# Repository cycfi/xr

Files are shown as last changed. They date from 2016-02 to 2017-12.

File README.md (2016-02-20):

# xr
XR Extended Response Pickups

The Cycfi XR Extended Response Pickups utilize low-impedance coils (Lo-Z 350Ω to 500Ω DCR) which 
inherently have full frequency response from 20Hz to 20kHz and beyond. Unlike traditional high-
impedance passive pickups there are no big peaks and dips in the spectrum, typically perceived as 
the pickup’s “character”. That does not mean that Lo-Z pickups lack character. In fact a Lo-Z coil’s 
characteristically wide bandwidth gives it a voice all its own. The pickups are very rich in harmonics, 
with uber-clean sounds, lots of overtones and crystal clear highs. They have a lot more harmonic 
content than even the bright Stratocaster pickup (which has frequency response that rolls off at 
around 5KHz.) On the low end of the audio spectrum you get tight, well-defined and focused bass 
all the way down to 20Hz.

This work is licensed under a [Creative Commons Attribution-NonCommercial 4.0 
International License](http://creativecommons.org/licenses/by-nc/4.0/).

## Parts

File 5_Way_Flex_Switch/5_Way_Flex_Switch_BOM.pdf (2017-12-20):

### 5 WAY FLEX SWITCH V1.2

Item | Description | Part Number | Packaging | Manufacturer | Location | Qty.
1 | 5 Way Switch | LSW56 | - | - | - | 1
2 | 2x7 Male Header | M20-9720745 (http://www.mouser.com/ProductDetail/Harwin/M20-9720745/) | 2.54mm | Harwin | H1 | 1
3 | 2x4 Male Header | M20-9720445 (http://www.mouser.ph/ProductDetail/Harwin/M20-9720445/) | 2.54mm | Harwin | H2 | 1
4 | 1x3 SMD Male Header | M20-8900305 (http://www.mouser.ph/ProductDetail/Harwin/M20-8900305/) | 2.54mm | Harwin | H3 | 1
5 | 4.7uF | GRM188R61C475KAAJD (http://www.mouser.com/ProductDetail/Murata-Electronics/GRM188R61C475KAAJD/) | SMD 0603 | Murata | C1 | 1
6 | 0.1uF | VJ0603Y104JXJPW1BC (http://www.mouser.com/ProductDetail/Vishay/VJ0603Y104JXJPW1BC/) | SMD 0603 | Vishay | C2 | 1
7 | Shunt | M7582-05 (http://www.mouser.com/ProductDetail/Harwin/M7582-05/) | 2.54mm | Harwin | - | 1

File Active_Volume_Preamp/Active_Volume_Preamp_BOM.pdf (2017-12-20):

ACTIVE VOLUME PREAMP V1.1
Item | Description | Part Number | Packaging | Manufacturer | Location | Qty.
1 | 25K Potentiometer | PDB241-GTR01-253A2 (http://www.mouser.com/ProductDetail/Bourns/PDB241-GTR01-253A2/) | - | Bourns | POT1 | 1
2 | 500 ohms Trimmer | TC33X-2-501E (http://www.mouser.com/ProductDetail/Bourns/TC33X-2-501E/?qs=uk4CKxxanjz26UifkfMmKw%3D%3D) | SMD | Bourns | TR1 | 1
3 | 2x7 Male Header RA | M20-9950745 (http://www.mouser.com/ProductDetail/Harwin/M20-9950745/) | 2.54mm TH | Harwin | H1 | 1
4 | Shunt | M7582-05 (http://www.mouser.com/ProductDetail/Harwin/M7582-05/) | 2.54mm | Harwin | - | 1

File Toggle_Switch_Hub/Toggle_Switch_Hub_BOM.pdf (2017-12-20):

TOGGLE SWITCH HUB V1.1
Item | Description | Part Number | Packaging | Manufacturer | Location | Qty.
1 | 2x5 Male Header | M20-9720545 (http://www.mouser.ph/ProductDetail/Harwin/M20-9720545/) | 2.54mm | Harwin | H1 | 1
2 | 2x4 Male Header | M20-9720445 (http://www.mouser.ph/ProductDetail/Harwin/M20-9720445/) | 2.54mm | Harwin | H2 | 1
3 | 1x8 Male Header | M20-9730845 (http://www.mouser.ph/Search/ProductDetail.aspx) | 2.54mm | Harwin | H3 | 2
4 | Terminal Block | 282837-4 (http://www.mouser.ph/Search/ProductDetail.aspx?R=282837-4virtualkey57110000virtualkey571-2828374) | 5.08mm | TE Connectivity | TB1 | 1
5 | 4.7uF | GRM188R61C475KAAJD (http://www.mouser.com/ProductDetail/Murata-Electronics/GRM188R61C475KAAJD/) | SMD 0603 | Murata | C1 | 1
6 | 0.1uF | VJ0603Y104JXJPW1BC (http://www.mouser.com/ProductDetail/Vishay/VJ0603Y104JXJPW1BC/) | SMD 0603 | Vishay | C2 | 1
7 | Shunt | M7582-05 (http://www.mouser.com/ProductDetail/Harwin/M7582-05/) | 2.54mm | Harwin | - | 4

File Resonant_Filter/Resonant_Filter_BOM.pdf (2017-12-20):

RESONANT FILTER
Item | Description | Part Number | Packaging | Manufacturer | Location | Qty.
1 | 100K Potentiometer | PDB182-GTR01-104B0 (http://www.mouser.ph/ProductDetail/Bourns/PDB182-GTR01-104B0/) | - | Bourns | - | 2
2 | 0.1uF | VJ0603Y104JXJPW1BC (http://www.mouser.ph/ProductDetail/Vishay-Vitramon/VJ0603Y104JXJPW1BC/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) | SMD 0603 | Vishay | C1, C3 | 2
3 | 4.7uF | C1608X5R1C475M080AC (http://www.mouser.ph/ProductDetail/TDK/C1608X5R1C475M080AC/) | SMD 0603 | TDK | C4 | 1
4 | 100pF | VJ0805A101GXAPW1BC (http://www.mouser.ph/ProductDetail/Vishay-Vitramon/VJ0805A101GXAPW1BC/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) | SMD 0805 | Vishay | C6 | 1
5 | 1uF | VJ0805Y105KXQTW1BC (http://www.mouser.ph/ProductDetail/Vishay-Vitramon/VJ0805Y105KXQTW1BC/) | SMD 0805 | Vishay | C2, C5 | 2
6 | 4.7K | CRCW04024K70JNED (http://www.mouser.ph/ProductDetail/Vishay-Dale/CRCW04024K70JNED/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) | SMD 0402 | Vishay | R7 | 1
7 | 20K | CRCW040220K0JNED (http://www.mouser.ph/ProductDetail/Vishay-Dale/CRCW040220K0JNED/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) | SMD 0402 | Vishay | R4 | 1
8 | 47K | CRCW040247K0JNED (http://www.mouser.ph/ProductDetail/Vishay-Dale/CRCW040247K0JNED/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) | SMD 0402 | Vishay | R6 | 1
9 | 60.4K | TNPW040260K4BEED (http://www.mouser.ph/ProductDetail/Vishay/TNPW040260K4BEED/) | SMD 0402 | Vishay | R5 | 1
10 | 100K | RT0402FRE07100KL (http://www.mouser.ph/ProductDetail/Yageo/RT0402FRE07100KL/) | SMD 0402 | Yageo | R2, R3 | 2
11 | 150K | CRCW0402150KFKED (http://www.mouser.ph/ProductDetail/Vishay-Dale/CRCW0402150KFKED/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) | SMD 0402 | Vishay | R1 | 1
12 | 100K | RT0402FRE07100KL (http://www.mouser.ph/ProductDetail/Yageo/RT0402FRE07100KL/) | SMD 0402 | Yageo | R10, R11 | 2
13 | 3.3K | RT0603FRE073K3L (http://www.mouser.ph/ProductDetail/Yageo/RT0603FRE073K3L/) | SMD 0603 | Yageo | R8, R9 | 2
14 | 3.3nF | VJ0805Y332JXACW1B (http://www.mouser.ph/ProductDetail/Vishay-Vitramon/VJ0805Y332JXACW1BC/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) | SMD 0805 | Vishay | C7, C8 | 2
15 | 2SC3324 | 2SC3324GRTE85LF (http://www.mouser.ph/ProductDetail/Toshiba/2SC3324GRTE85LF/) | SOT 23 | Toshiba | T1 | 1
16 | OPA209 | OPA209AIDBVR (http://www.mouser.ph/ProductDetail/Texas-Instruments/OPA209AIDBVR/) | SOT23-5 | Texas Instruments | U1 | 1
17 | 1x8 Male Header, RA | M20-9960845 (http://www.mouser.ph/ProductDetail/Harwin/M20-9960845/) | 2.54mm | Harwin | H1 | 1
18 | 1x4 Male Header | M20-9730445 (http://www.mouser.ph/ProductDetail/Harwin/M20-9730445/) | 2.54mm | Harwin | H2 | 1

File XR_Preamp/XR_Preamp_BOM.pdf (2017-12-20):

XR UNIVERSAL PREAMP V.1.5
Item | Description | Part Number | Packaging | Manufacturer | Location | Qty.
1 | 0.1uF | GRM155R71C104KA88D (http://www.mouser.com/Search/ProductDetail.aspx) | SMD 0402 | Murata | C4 | 1
2 | 100pF | C0402C101K4GACTU (http://www.mouser.com/Search/ProductDetail.aspx) | SMD 0402 | Kemet | C2 | 1
3 | 10k | RC0402FR-0710KL (http://www.mouser.com/Search/ProductDetail.aspx) | SMD 0402 | Yageo | R4, R5 | 2
4 | 1k | RC0402FR-071KL (http://www.mouser.com/Search/ProductDetail.aspx) | SMD 0402 | Yageo | R7 | 1
5 | 200k | MCS04020C2003FE000 (http://www.mouser.com/ProductDetail/Vishay-Beyschlag/MCS04020C2003FE000/) | SMD 0402 | Vishay | R1 | 1
6 | 22k | RR0510P-223-D (http://www.mouser.com/ProductDetail/Susumu/RR0510P-223-D/) | SMD 0402 | Susumu | R3 | 1
7 | 27k | RR0510P-273-D (http://www.mouser.com/ProductDetail/Susumu/RR0510P-273-D/) | SMD 0402 | Susumu | R2 | 1
8 | 2SC3324 | 2SC3324GRTE85LF (http://www.mouser.com/Search/ProductDetail.aspx) | SOT23 | Toshiba | T1, T2 | 2
9 | 4.7k | RR0510P-472-D (http://www.mouser.com/ProductDetail/Susumu/RR0510P-472-D/) | SMD 0402 | Susumu | R6 | 1
10 | 4.7uF | ZRB15XR61A475ME01D (http://www.mouser.com/ProductDetail/Murata-Electronics/ZRB15XR61A475ME01D/) | SMD 0402 | Murata | C5 | 1
11 | 4.7uF | GRM188R61C475KAAJD (http://www.mouser.com/Search/ProductDetail.aspx) | SMD 0603 | Murata | C1, C3 | 2

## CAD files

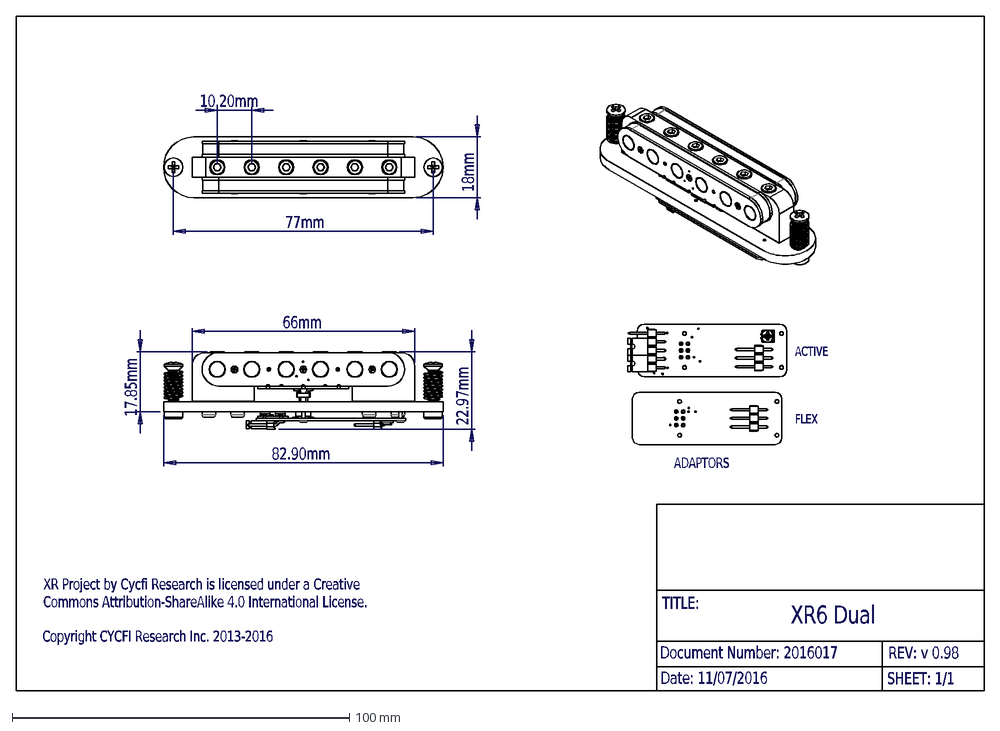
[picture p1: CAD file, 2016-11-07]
CAD_Drawings/XR_Dual/XR6_Dual_Drawing.dxf
FLEX
XR Project by Cycfi Research is licensed under a Creative
Commons Attribution-ShareAlike 4.0 International License.
Copyright CYCFI Research Inc. 2013-2016
XR6 Dual
TITLE:
Document Number: 2016017
Date: 11/07/2016
REV: v 0.98
SHEET: 1/1
66mm
82.90mm
22.97mm
17.85mm
77mm
10.20mm
18mm
ACTIVE
ADAPTORS

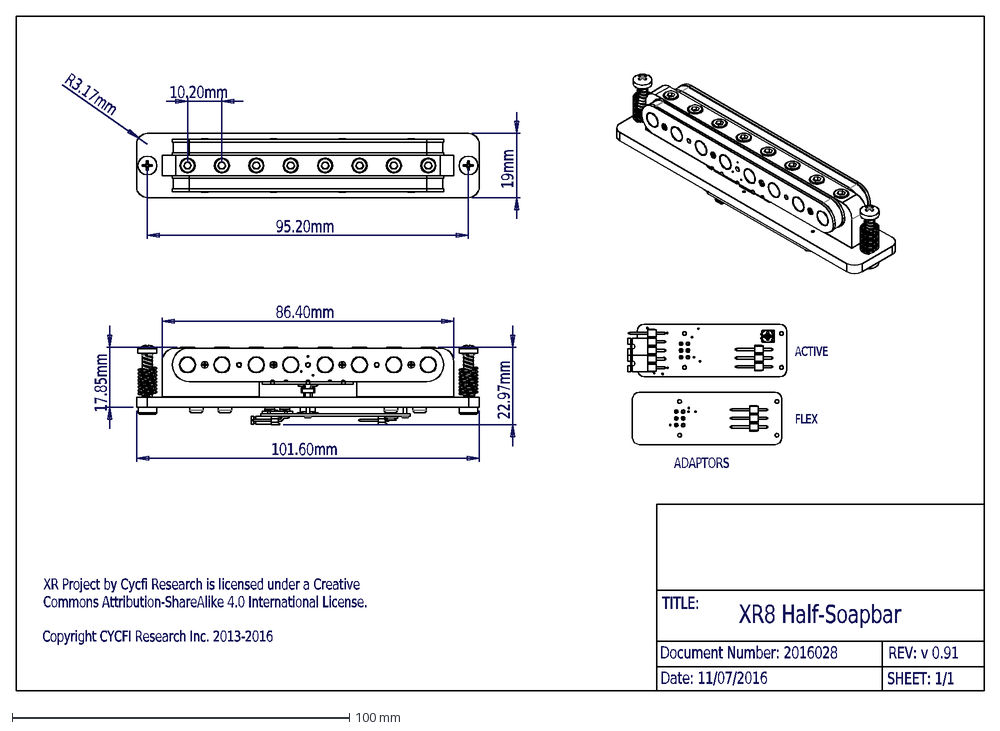
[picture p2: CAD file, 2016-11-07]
CAD_Drawings/XR_Half_Soapbar/XR8_Half_Soapbar_Drawing.dxf
FLEX
XR Project by Cycfi Research is licensed under a Creative
Commons Attribution-ShareAlike 4.0 International License.
Copyright CYCFI Research Inc. 2013-2016
XR8 Half-Soapbar
TITLE:
Document Number: 2016028
Date: 11/07/2016
REV: v 0.91
SHEET: 1/1
22.97mm
86.40mm
17.85mm
101.60mm
10.20mm
95.20mm
19mm
R3.17mm
ACTIVE
ADAPTORS

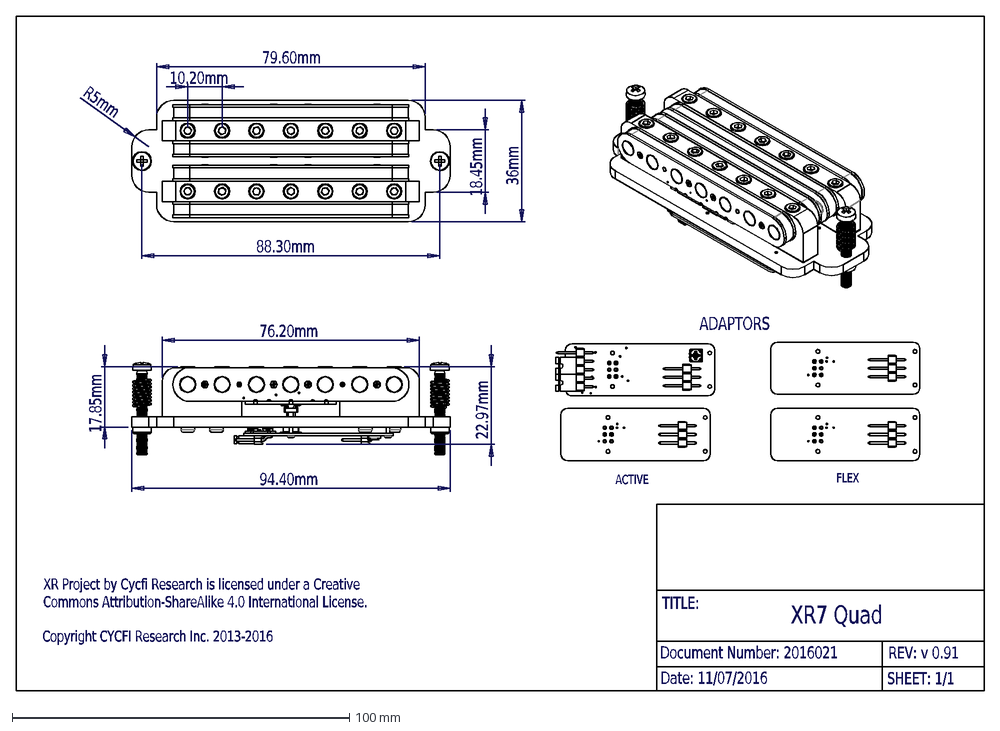
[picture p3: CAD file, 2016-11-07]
CAD_Drawings/XR_Quad/XR7_Quad_Drawing.dxf
FLEX
XR Project by Cycfi Research is licensed under a Creative
Commons Attribution-ShareAlike 4.0 International License.
Copyright CYCFI Research Inc. 2013-2016
XR7 Quad
TITLE:
Document Number: 2016021
Date: 11/07/2016
REV: v 0.91
SHEET: 1/1
94.40mm
76.20mm
22.97mm
17.85mm
88.30mm
10.20mm
79.60mm
18.45mm
36mm
R5mm
ACTIVE
ADAPTORS

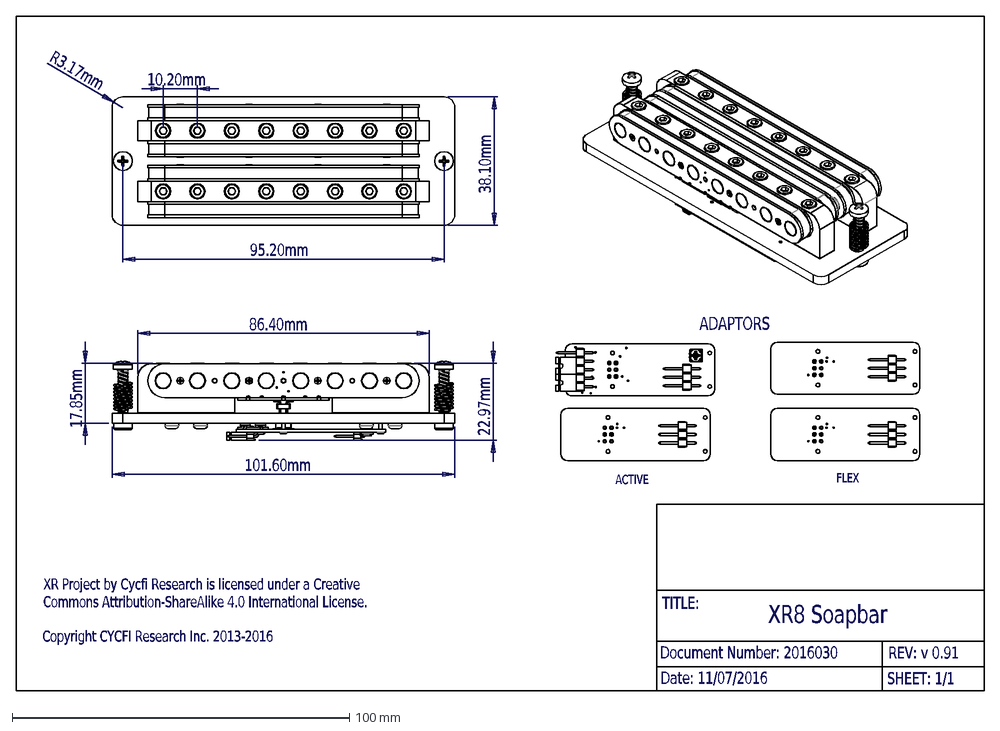
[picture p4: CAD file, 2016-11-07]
CAD_Drawings/XR_Soapbar/XR8_Soapbar_Drawing.DXF
FLEX
XR Project by Cycfi Research is licensed under a Creative
Commons Attribution-ShareAlike 4.0 International License.
Copyright CYCFI Research Inc. 2013-2016
XR8 Soapbar
TITLE:
Document Number: 2016030
Date: 11/07/2016
REV: v 0.91
SHEET: 1/1
86.40mm
22.97mm
101.60mm
17.85mm
10.20mm
38.10mm
R3.17mm
95.20mm
ACTIVE
ADAPTORS

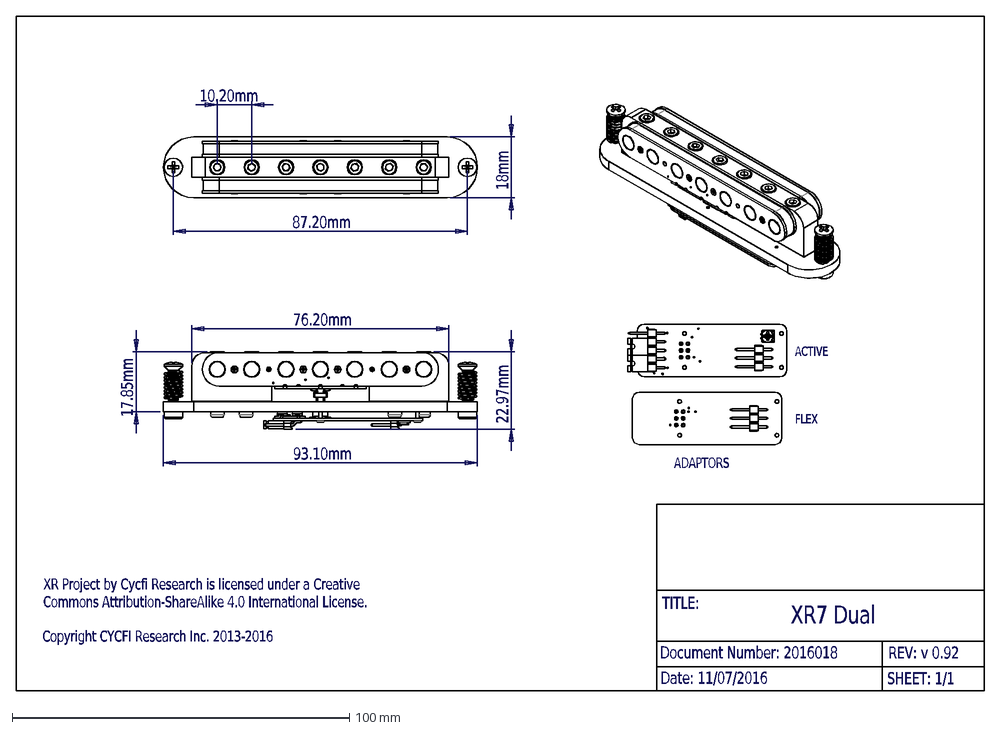
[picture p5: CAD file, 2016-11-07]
CAD_Drawings/XR_Dual/XR7_Dual_Drawing.dxf
FLEX
XR Project by Cycfi Research is licensed under a Creative
Commons Attribution-ShareAlike 4.0 International License.
Copyright CYCFI Research Inc. 2013-2016
XR7 Dual
TITLE:
Document Number: 2016018
Date: 11/07/2016
REV: v 0.92
SHEET: 1/1
76.20mm
93.10mm
22.97mm
17.85mm
87.20mm
10.20mm
18mm
ACTIVE
ADAPTORS

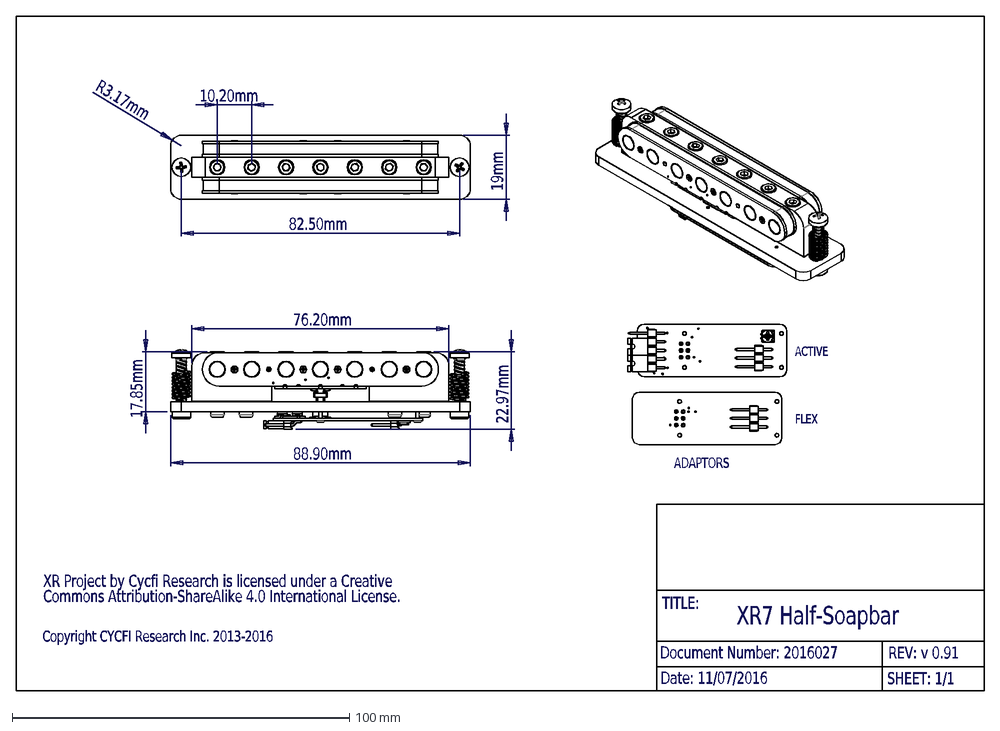
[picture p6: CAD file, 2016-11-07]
CAD_Drawings/XR_Half_Soapbar/XR7_Half_Soapbar_Drawing.dxf
FLEX
XR Project by Cycfi Research is licensed under a Creative
Commons Attribution-ShareAlike 4.0 International License.
Copyright CYCFI Research Inc. 2013-2016
XR7 Half-Soapbar
TITLE:
Document Number: 2016027
Date: 11/07/2016
REV: v 0.91
SHEET: 1/1
76.20mm
22.97mm
17.85mm
88.90mm
10.20mm
19mm
82.50mm
R3.17mm
ACTIVE
ADAPTORS

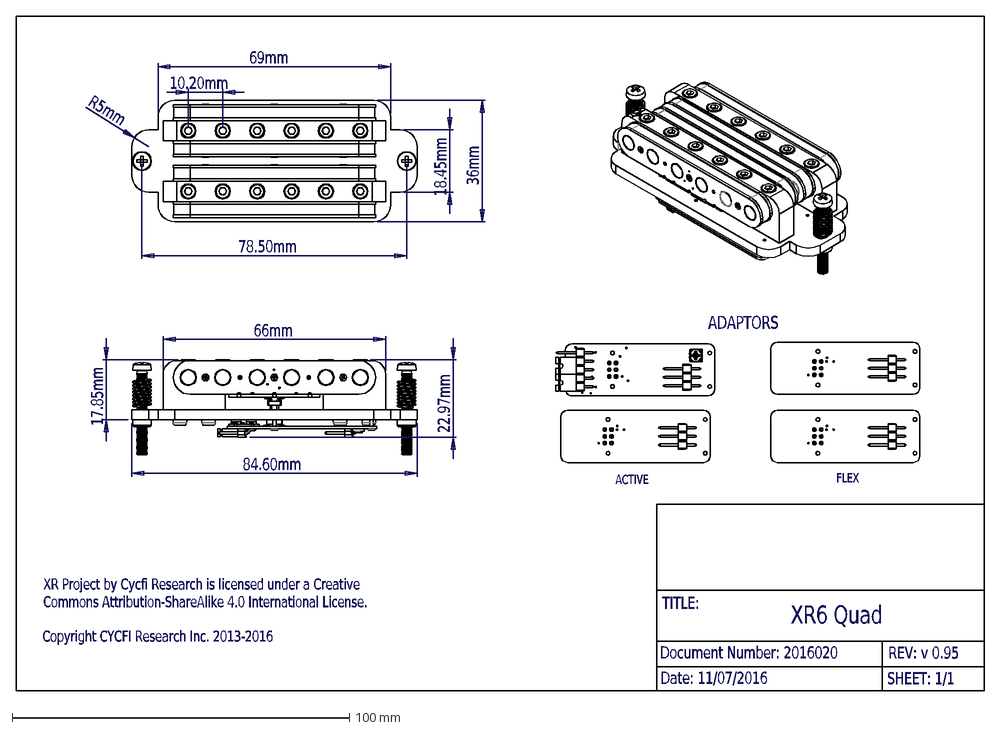
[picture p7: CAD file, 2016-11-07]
CAD_Drawings/XR_Quad/XR6_Quad_Drawing.dxf
FLEX
XR Project by Cycfi Research is licensed under a Creative
Commons Attribution-ShareAlike 4.0 International License.
Copyright CYCFI Research Inc. 2013-2016
XR6 Quad
TITLE:
Document Number: 2016020
Date: 11/07/2016
REV: v 0.95
SHEET: 1/1
66mm
22.97mm
84.60mm
17.85mm
10.20mm
69mm
18.45mm
36mm
78.50mm
R5mm
ACTIVE
ADAPTORS

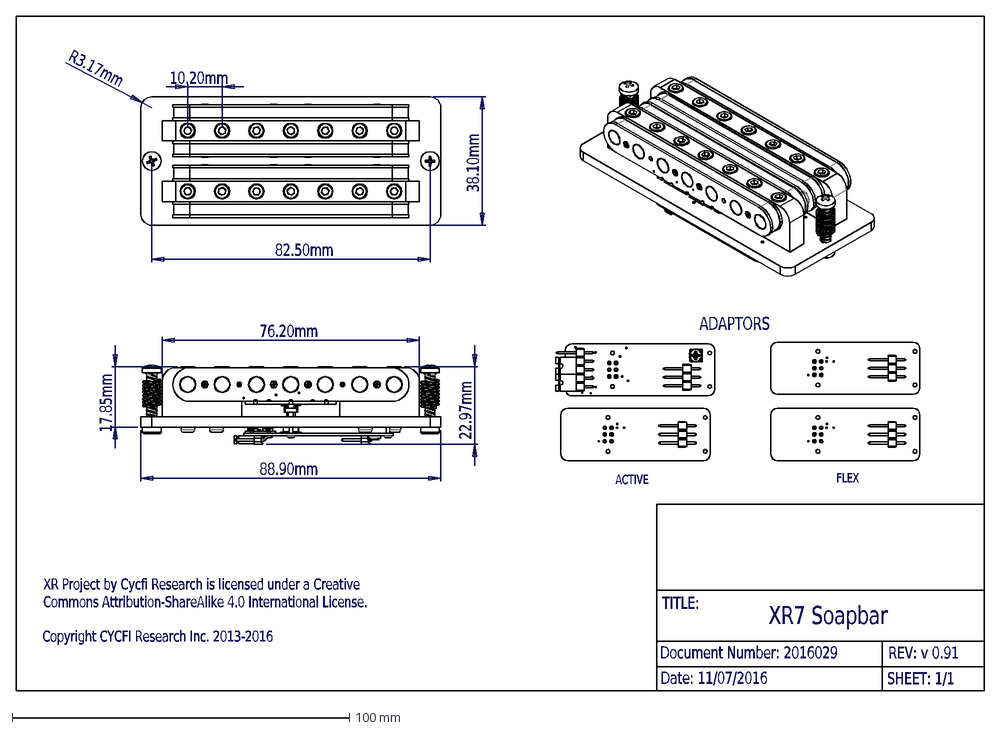
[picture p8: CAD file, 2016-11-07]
CAD_Drawings/XR_Soapbar/XR7_Soapbar_Drawing.DXF
FLEX
XR Project by Cycfi Research is licensed under a Creative
Commons Attribution-ShareAlike 4.0 International License.
Copyright CYCFI Research Inc. 2013-2016
XR7 Soapbar
TITLE:
Document Number: 2016029
Date: 11/07/2016
REV: v 0.91
SHEET: 1/1
76.20mm
22.97mm
88.90mm
17.85mm
10.20mm
38.10mm
82.50mm
R3.17mm
ACTIVE
ADAPTORS

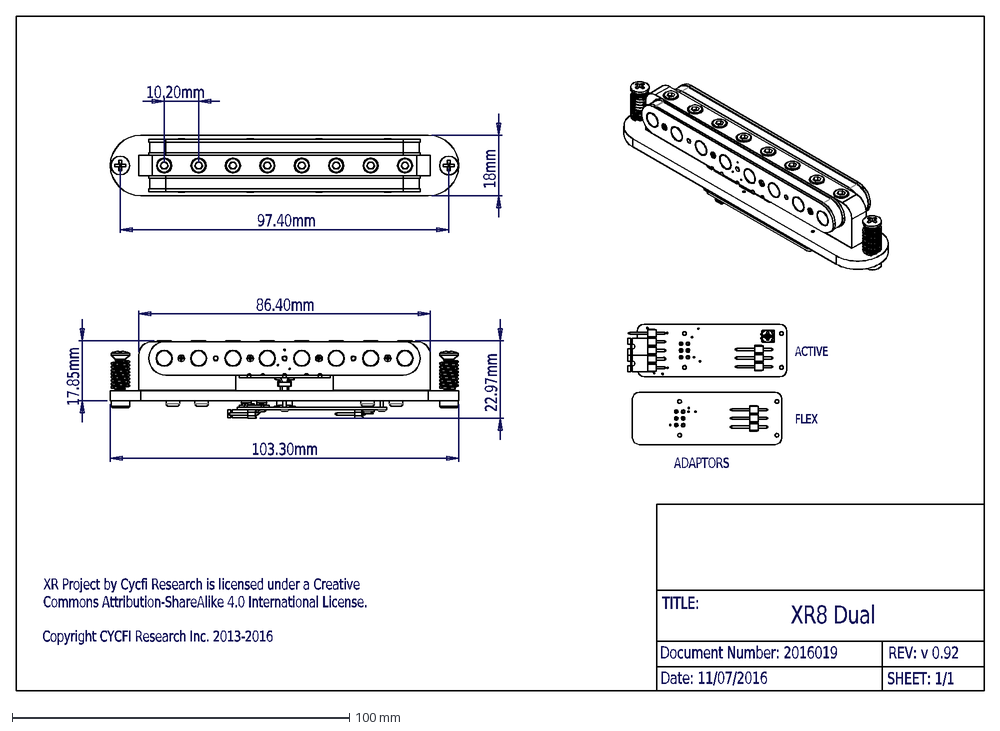
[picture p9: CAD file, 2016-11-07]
CAD_Drawings/XR_Dual/XR8_Dual_Drawing.dxf
FLEX
XR Project by Cycfi Research is licensed under a Creative
Commons Attribution-ShareAlike 4.0 International License.
Copyright CYCFI Research Inc. 2013-2016
XR8 Dual
TITLE:
Document Number: 2016019
Date: 11/07/2016
REV: v 0.92
SHEET: 1/1
17.85mm
22.97mm
86.40mm
103.30mm
97.40mm
10.20mm
18mm
ACTIVE
ADAPTORS

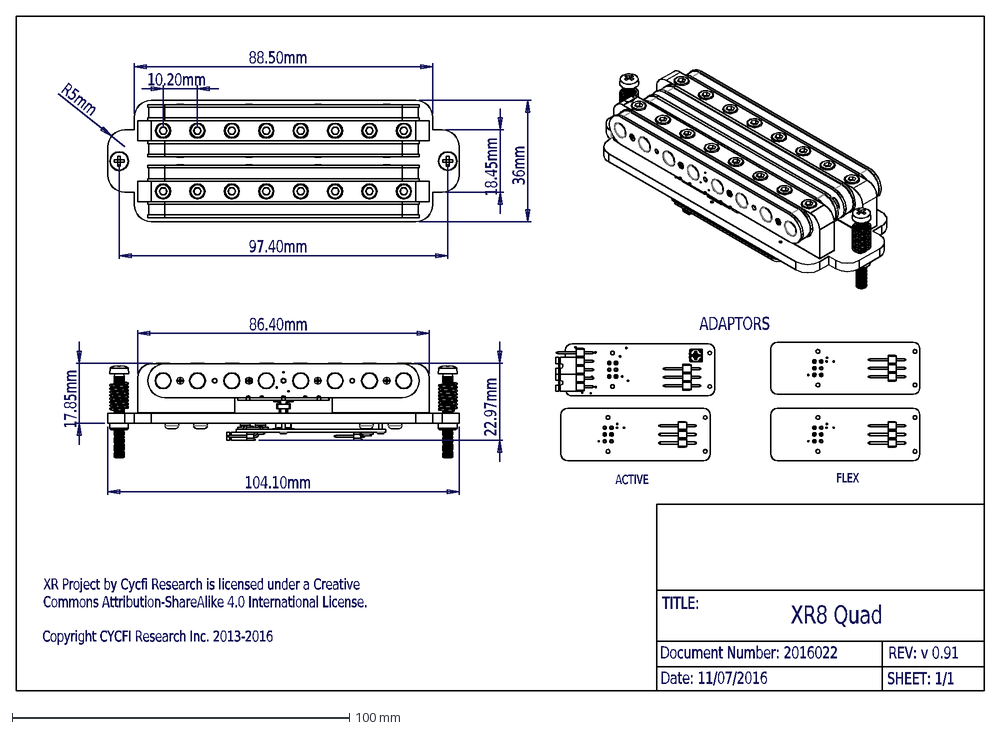
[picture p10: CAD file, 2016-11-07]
CAD_Drawings/XR_Quad/XR8_Quad_Drawing.dxf
FLEX
XR Project by Cycfi Research is licensed under a Creative
Commons Attribution-ShareAlike 4.0 International License.
Copyright CYCFI Research Inc. 2013-2016
XR8 Quad
TITLE:
Document Number: 2016022
Date: 11/07/2016
REV: v 0.91
SHEET: 1/1
86.40mm
104.10mm
17.85mm
22.97mm
97.40mm
88.50mm
10.20mm
36mm
18.45mm
R5mm
ACTIVE
ADAPTORS

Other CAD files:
CAD_Drawings/Baseplate/Half_Soapbar.DXF
CAD_Drawings/Baseplate/Soapbar.dxf
CAD_Drawings/Baseplate/Dual.dxf
CAD_Drawings/Baseplate/Quad.dxf

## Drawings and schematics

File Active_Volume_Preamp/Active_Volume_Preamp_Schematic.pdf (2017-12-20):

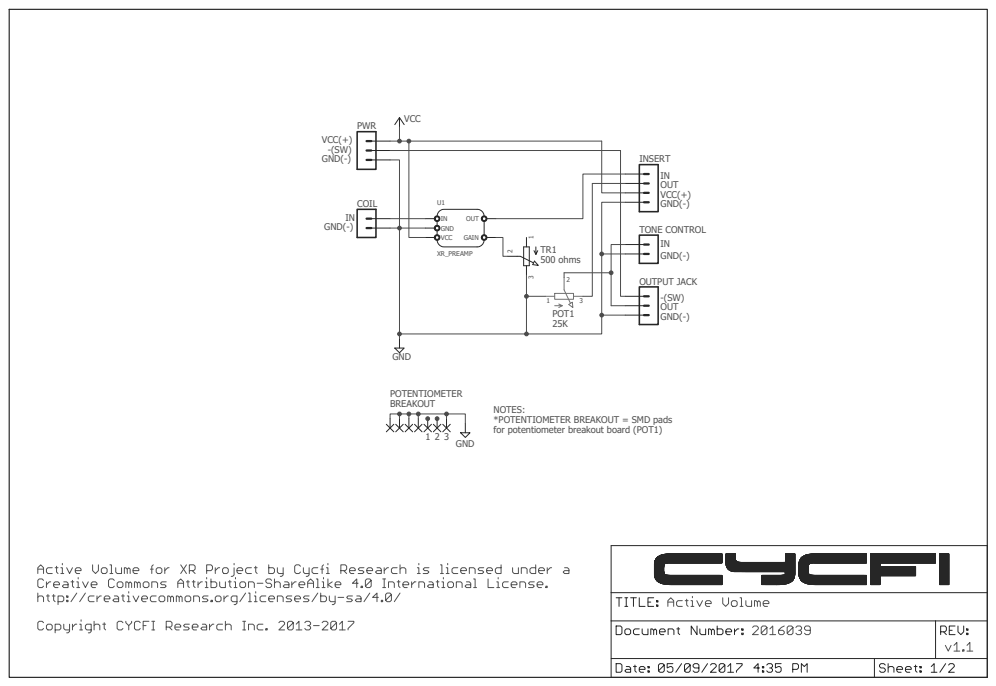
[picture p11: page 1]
GND; VCC; POTENTIOMETER BREAKOUT; POT1 25K; VCC(+); GND(-); IN OUT VCC(+) GND(-); -(SW) OUT GND(-); PWR; INSERT; OUTPUT JACK; COIL; TONE CONTROL IN GND(-); IN GND(-); 500 ohms; IN GND VCC; OUT; GAIN; XR_PREAMP

NOTES:
*POTENTIOMETER BREAKOUT = SMD pads
for potentiometer breakout board (POT1)

# OUTPUT HEADERS

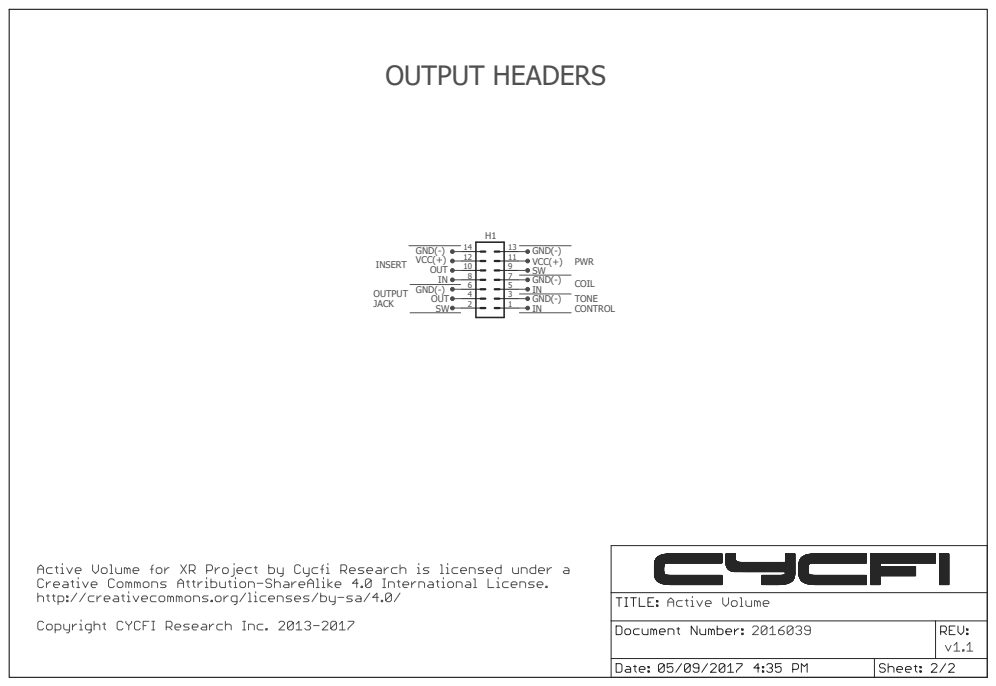
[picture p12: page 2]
OUT; GND(-); VCC(+); INSERT; OUTPUT JACK; PWR; TONE CONTROL; COIL

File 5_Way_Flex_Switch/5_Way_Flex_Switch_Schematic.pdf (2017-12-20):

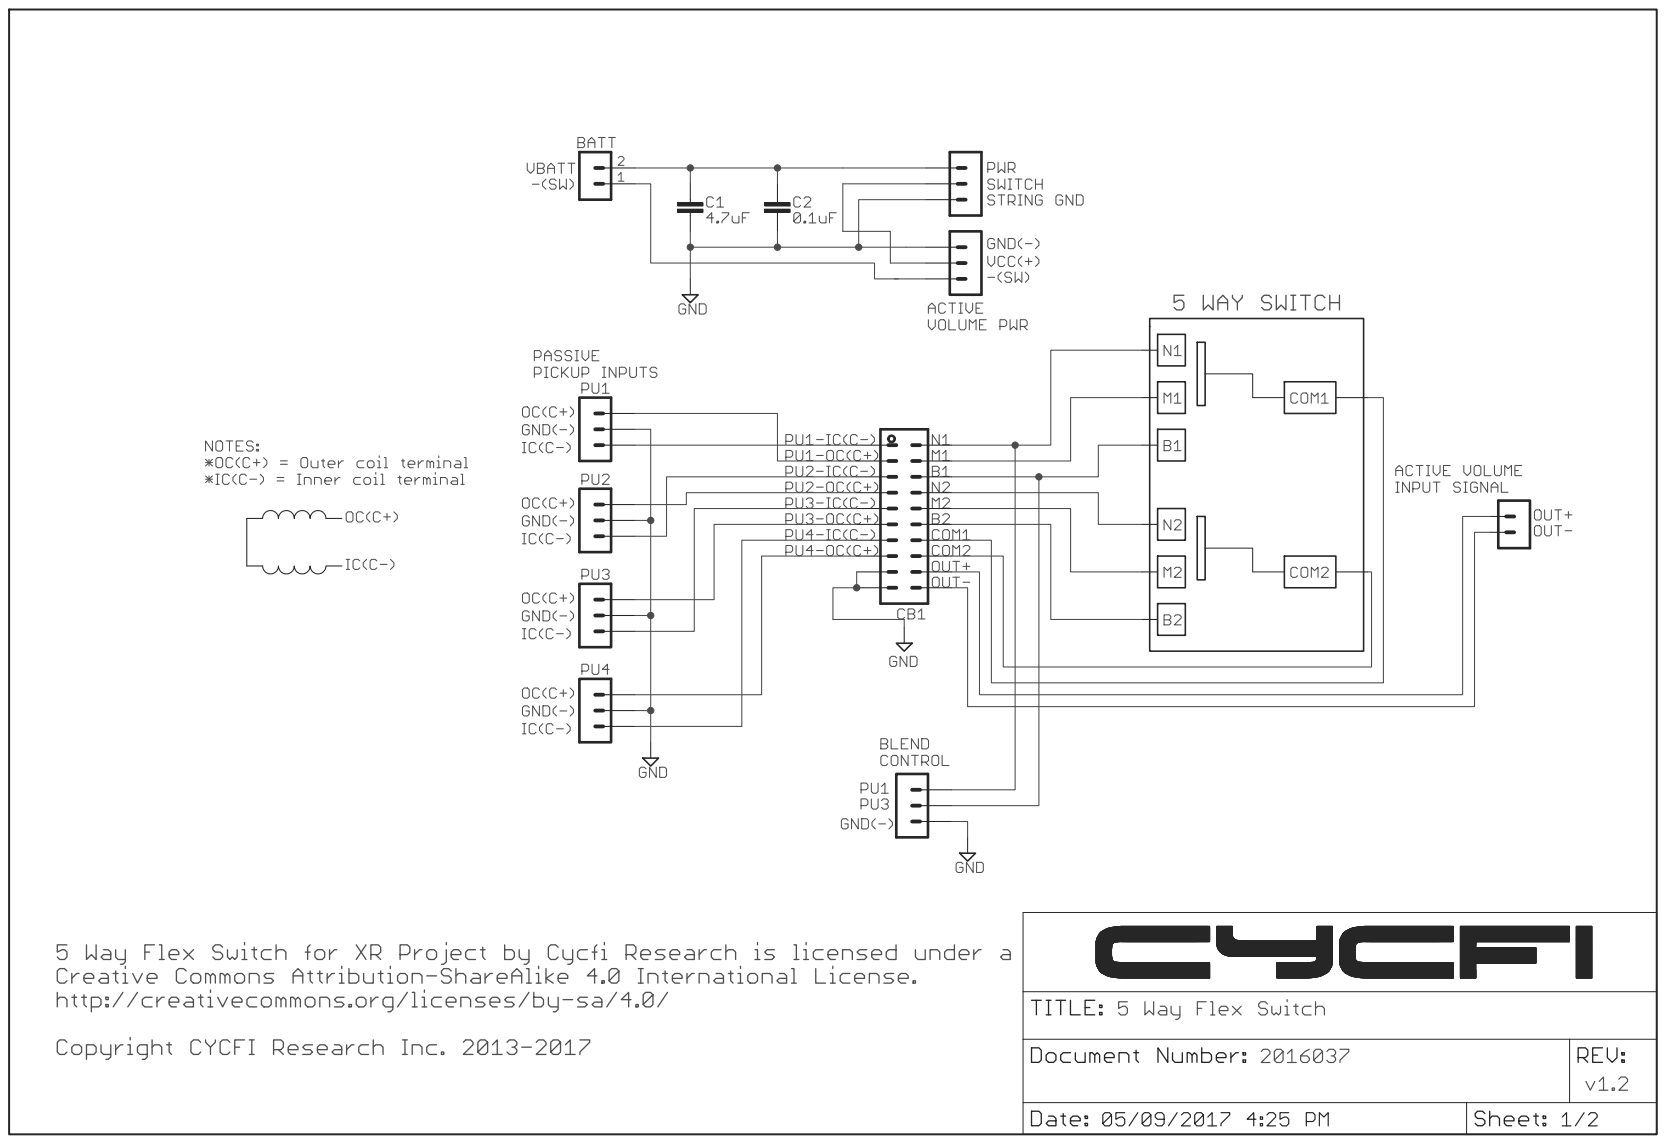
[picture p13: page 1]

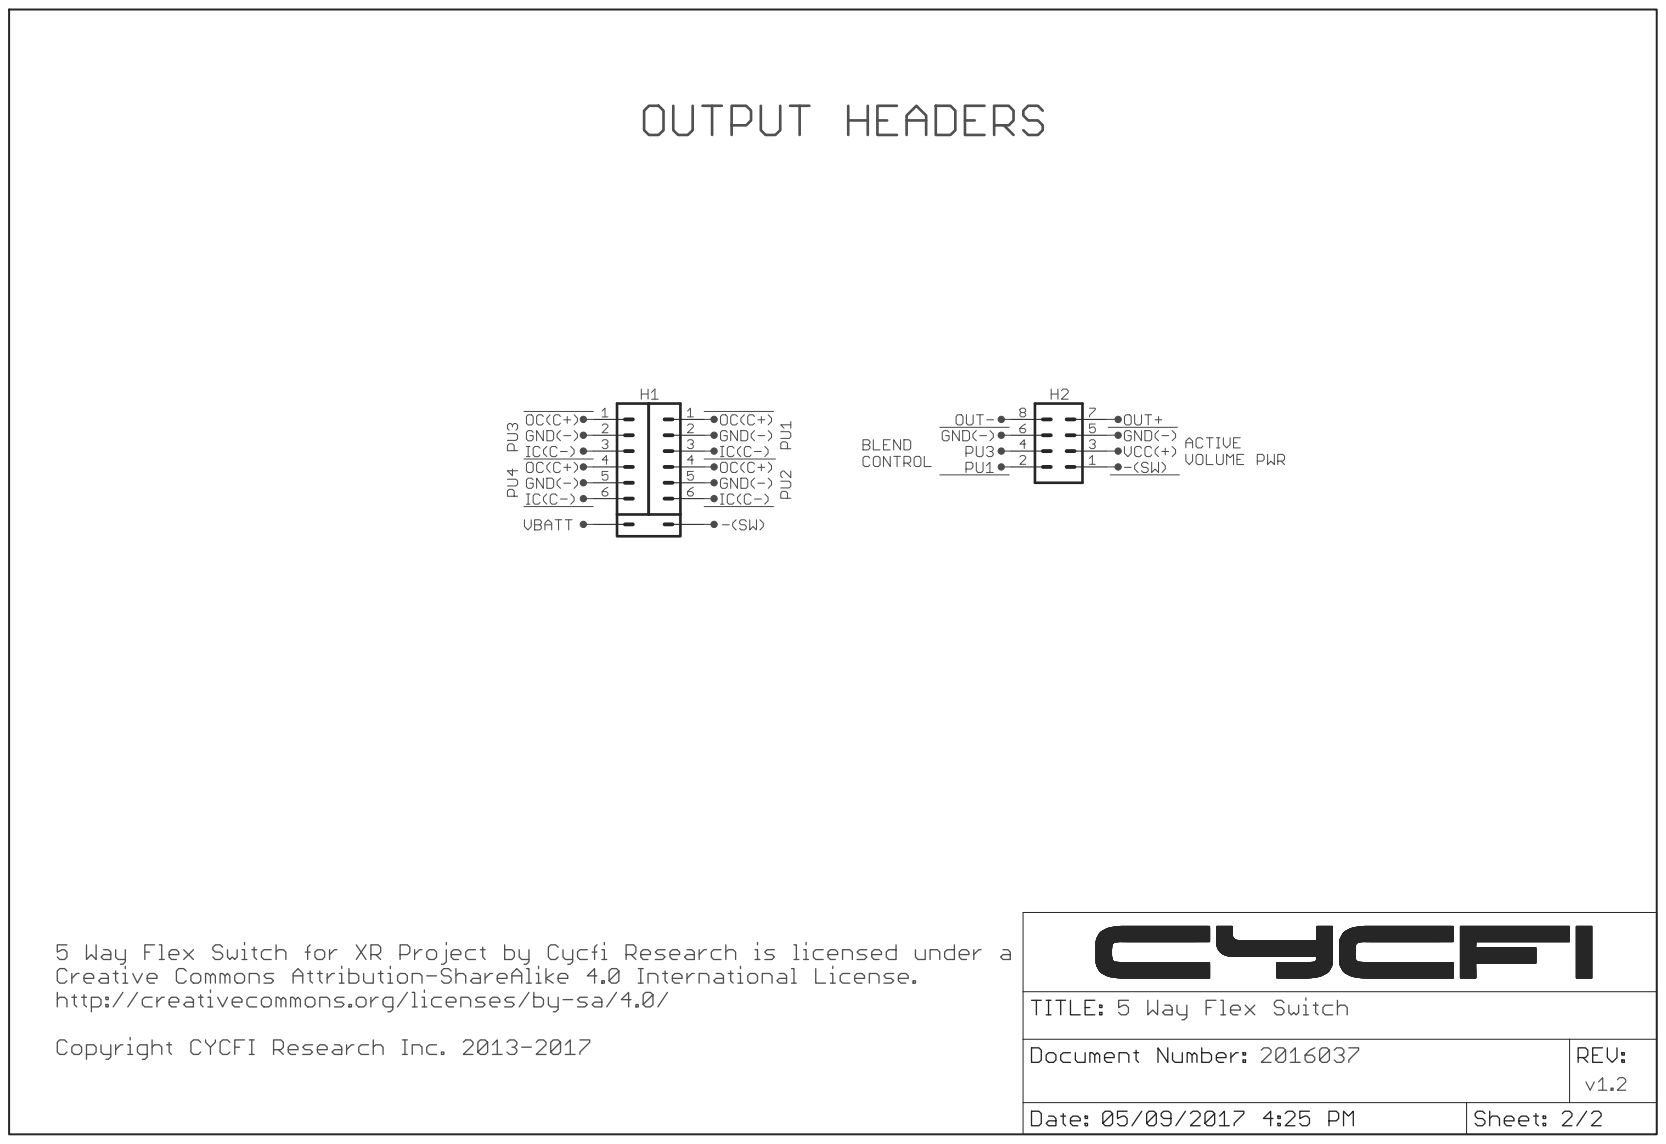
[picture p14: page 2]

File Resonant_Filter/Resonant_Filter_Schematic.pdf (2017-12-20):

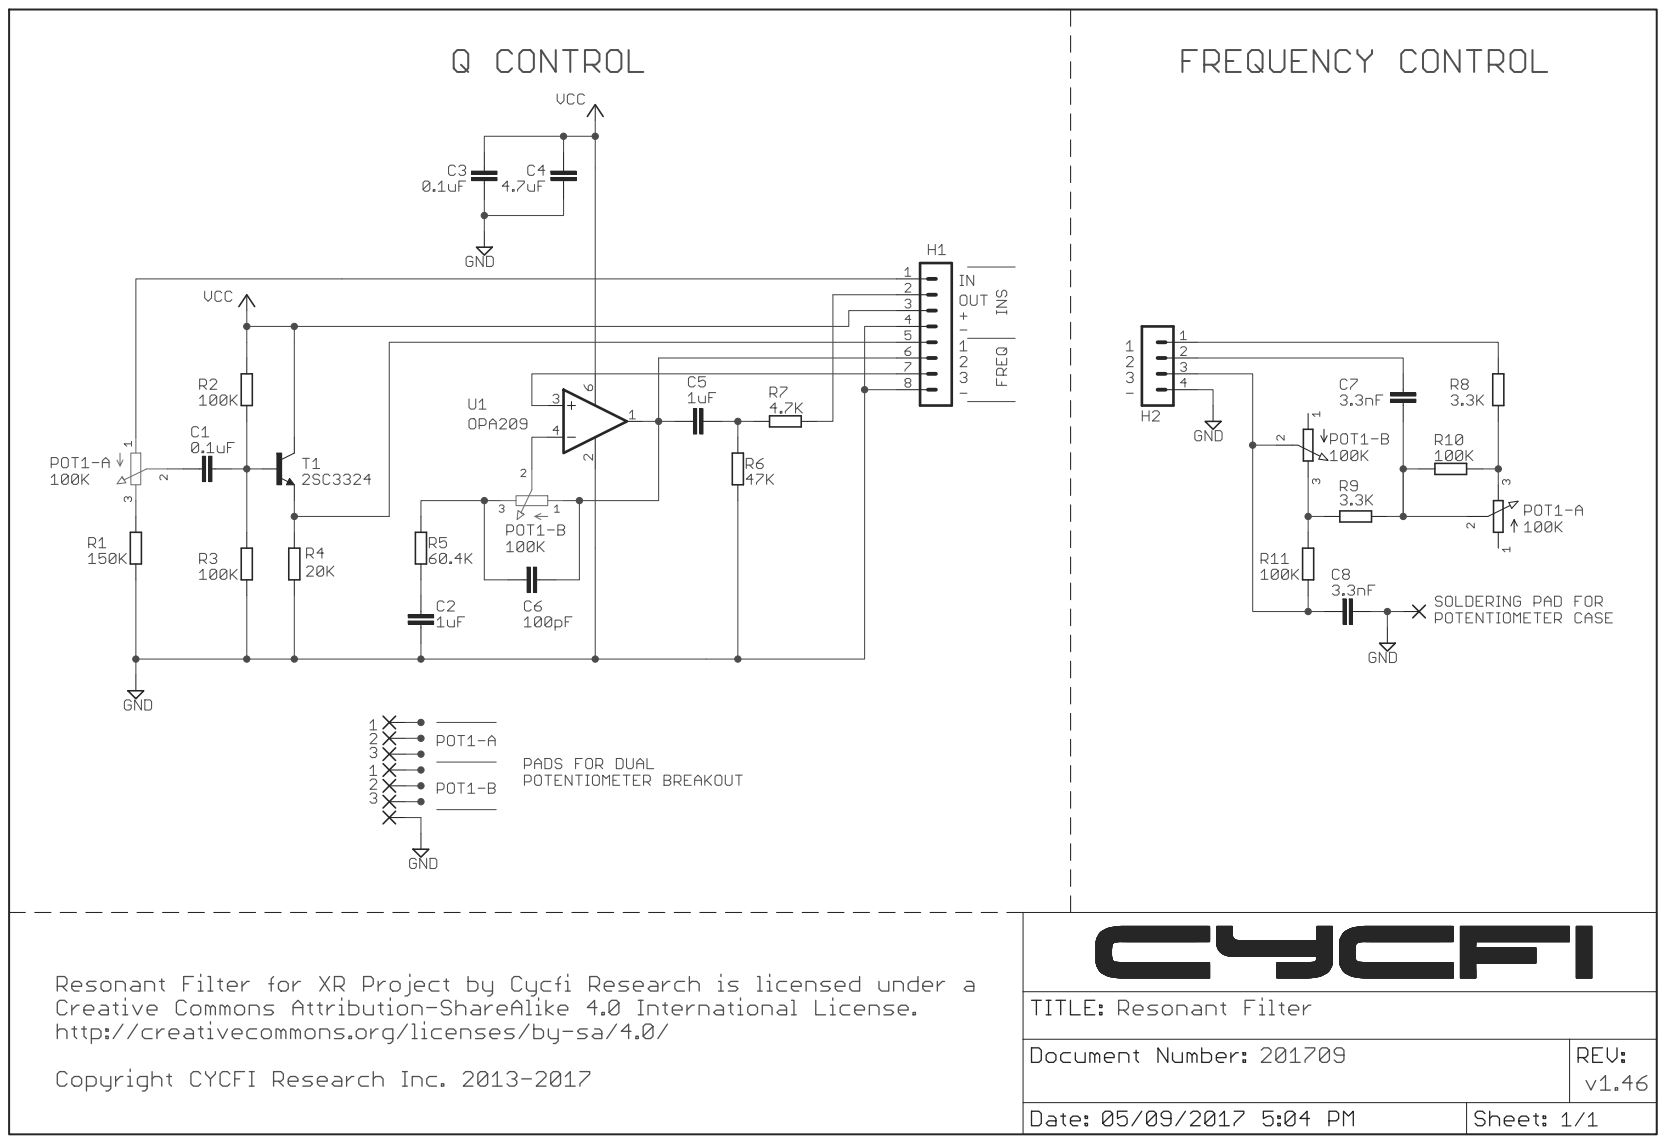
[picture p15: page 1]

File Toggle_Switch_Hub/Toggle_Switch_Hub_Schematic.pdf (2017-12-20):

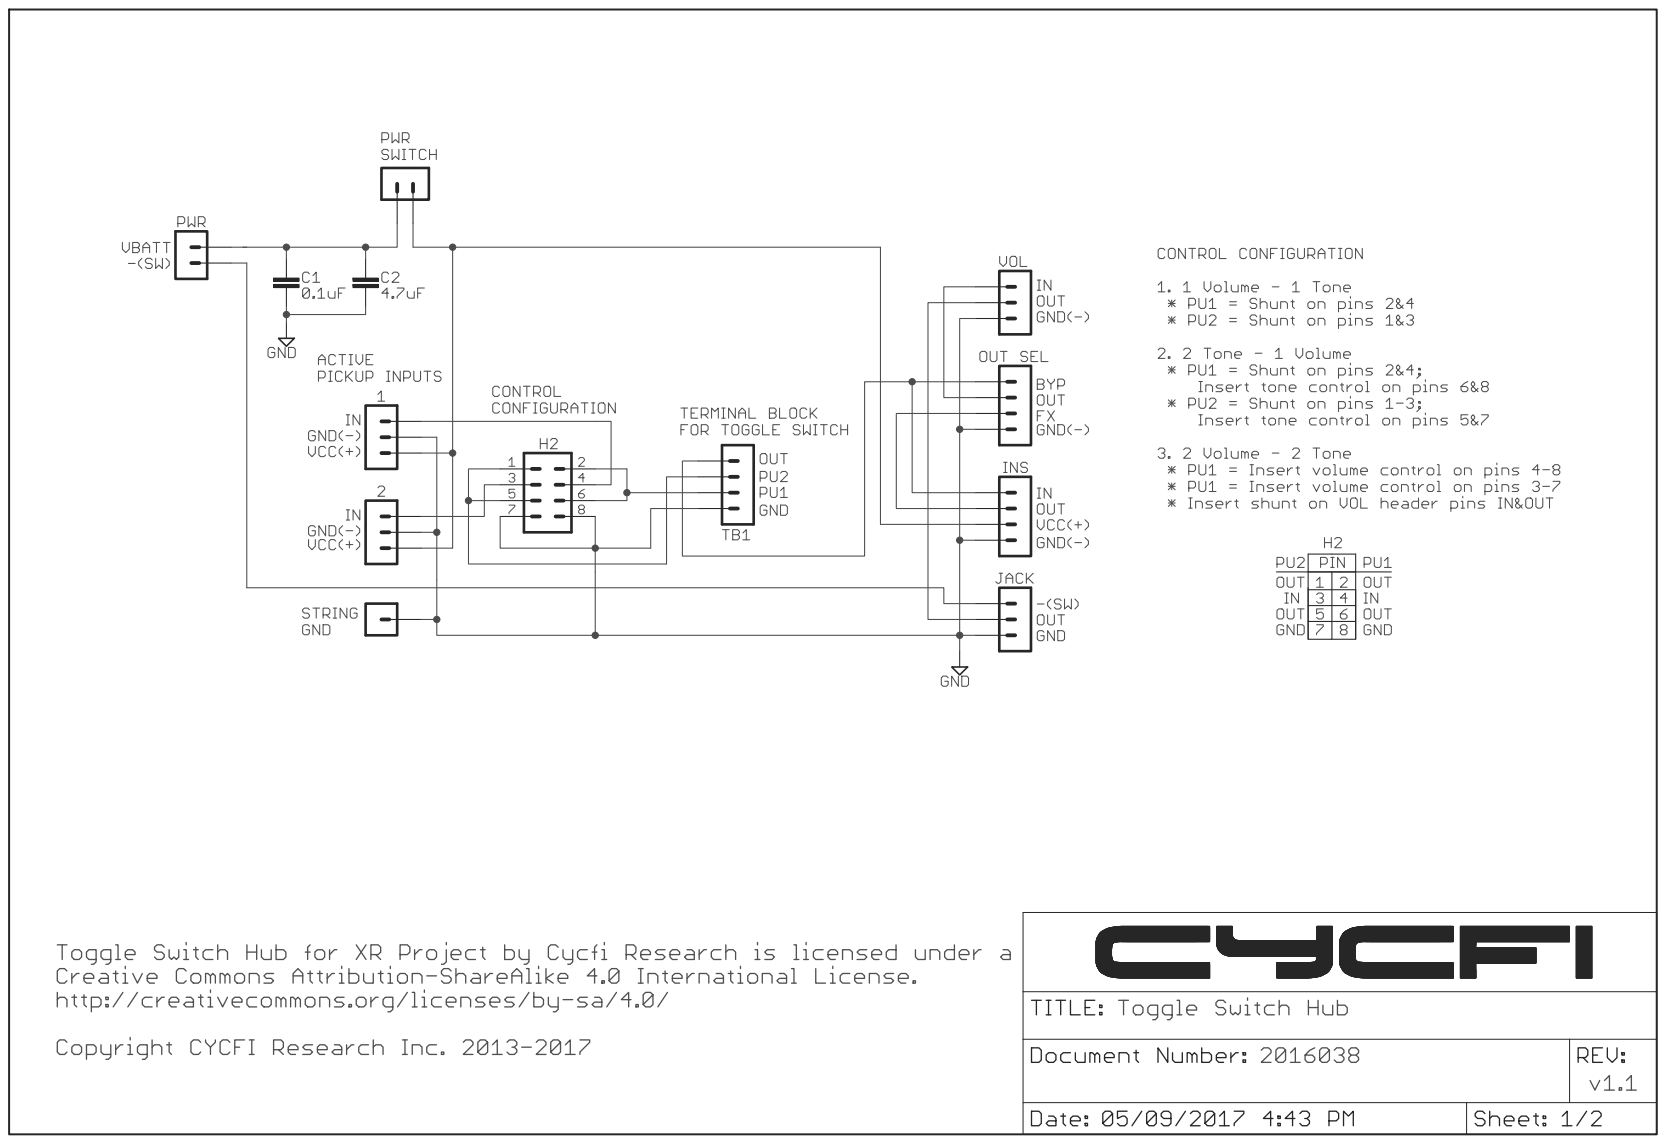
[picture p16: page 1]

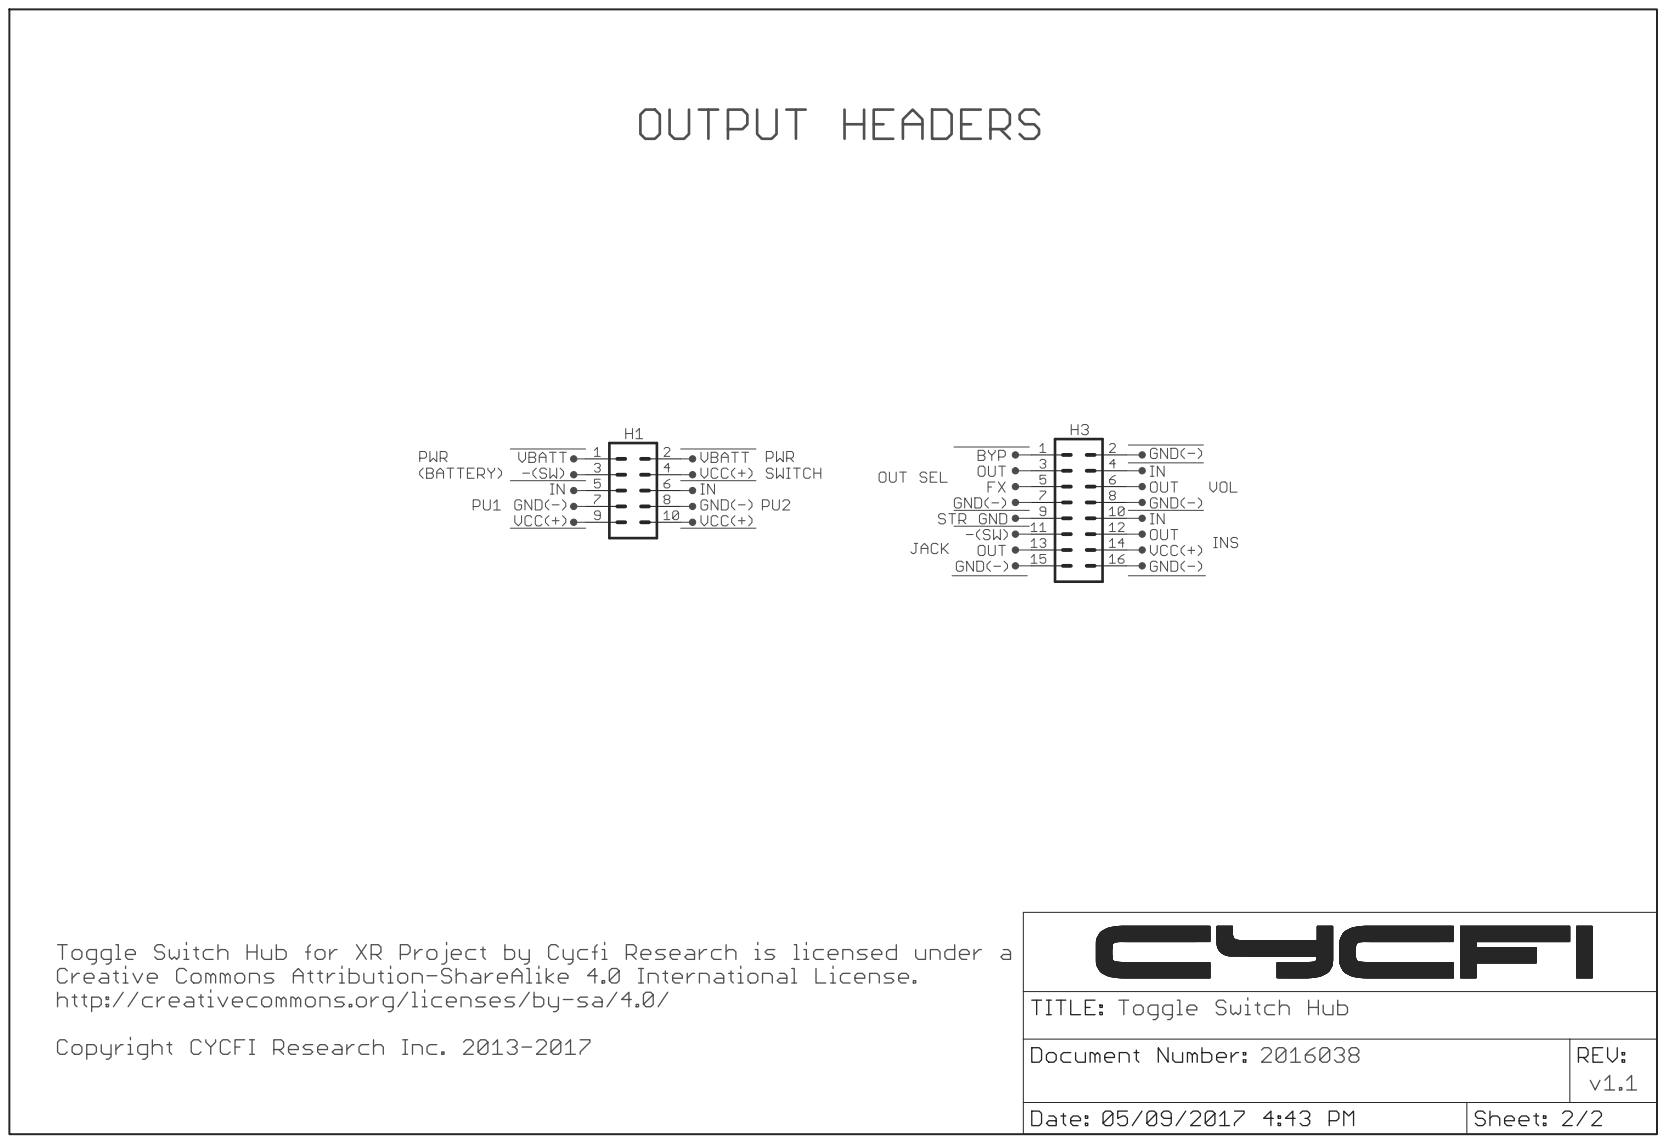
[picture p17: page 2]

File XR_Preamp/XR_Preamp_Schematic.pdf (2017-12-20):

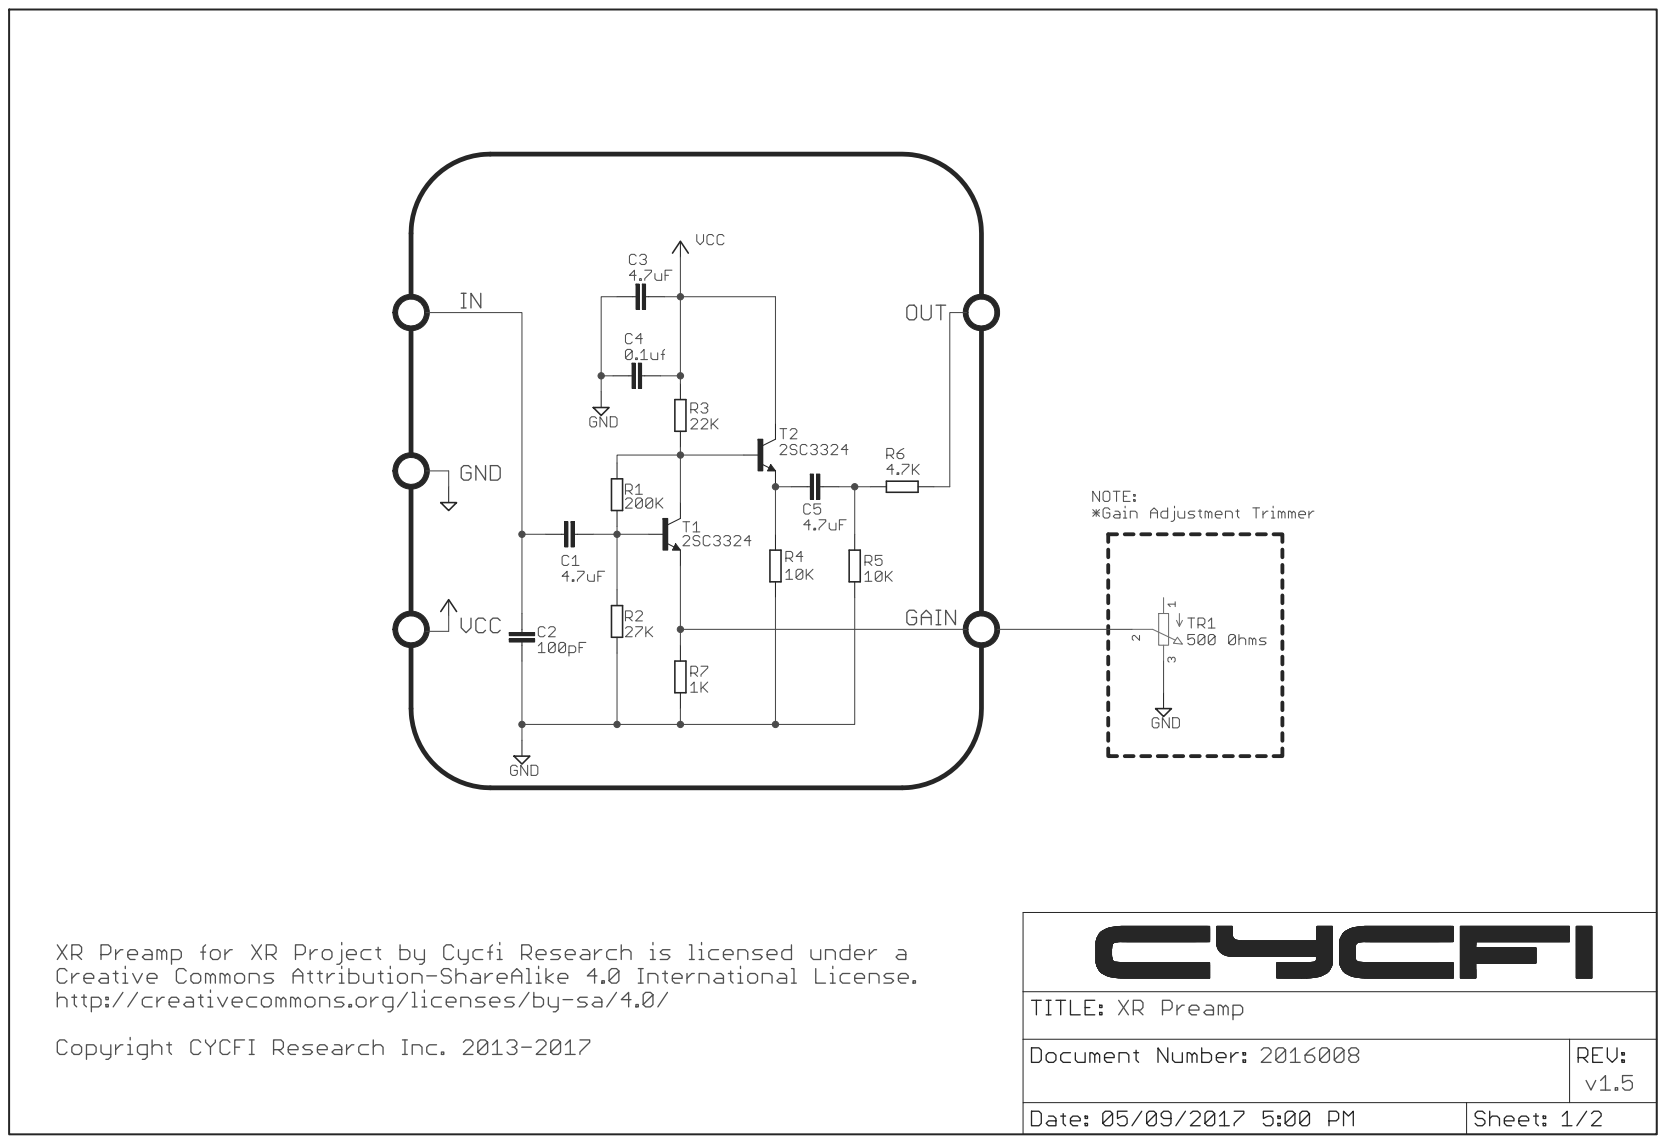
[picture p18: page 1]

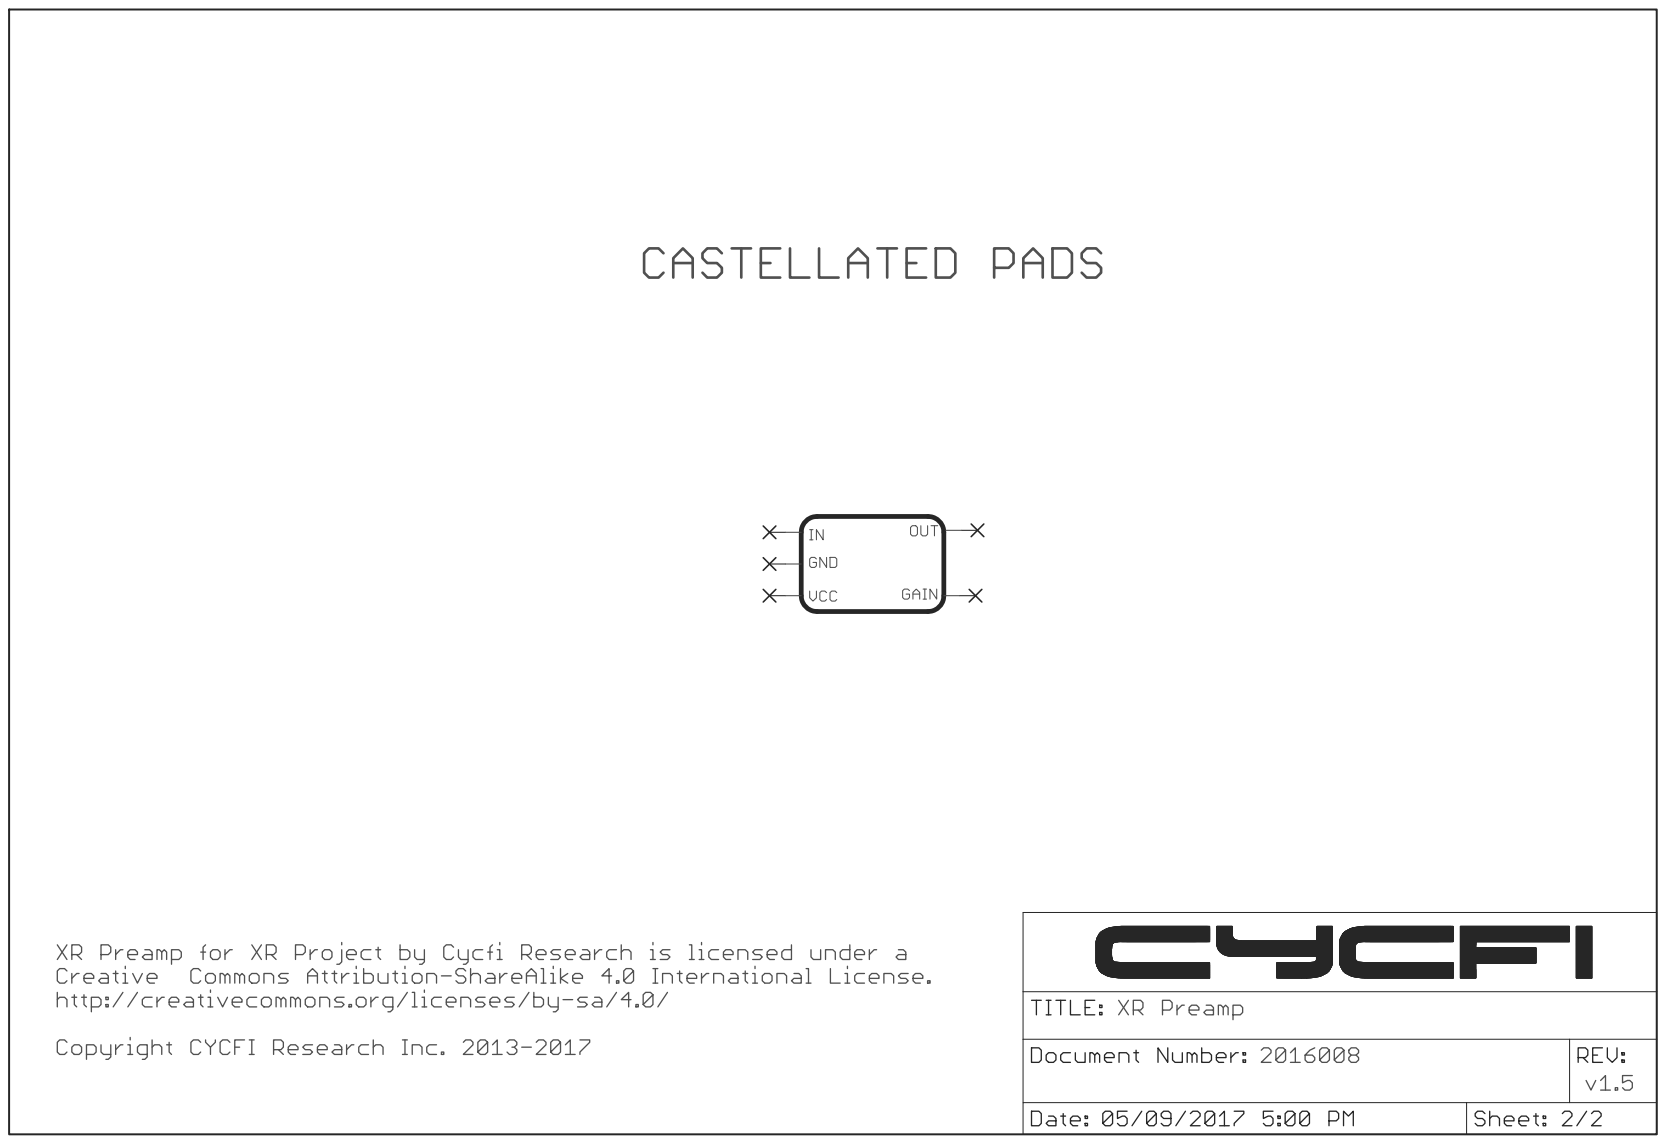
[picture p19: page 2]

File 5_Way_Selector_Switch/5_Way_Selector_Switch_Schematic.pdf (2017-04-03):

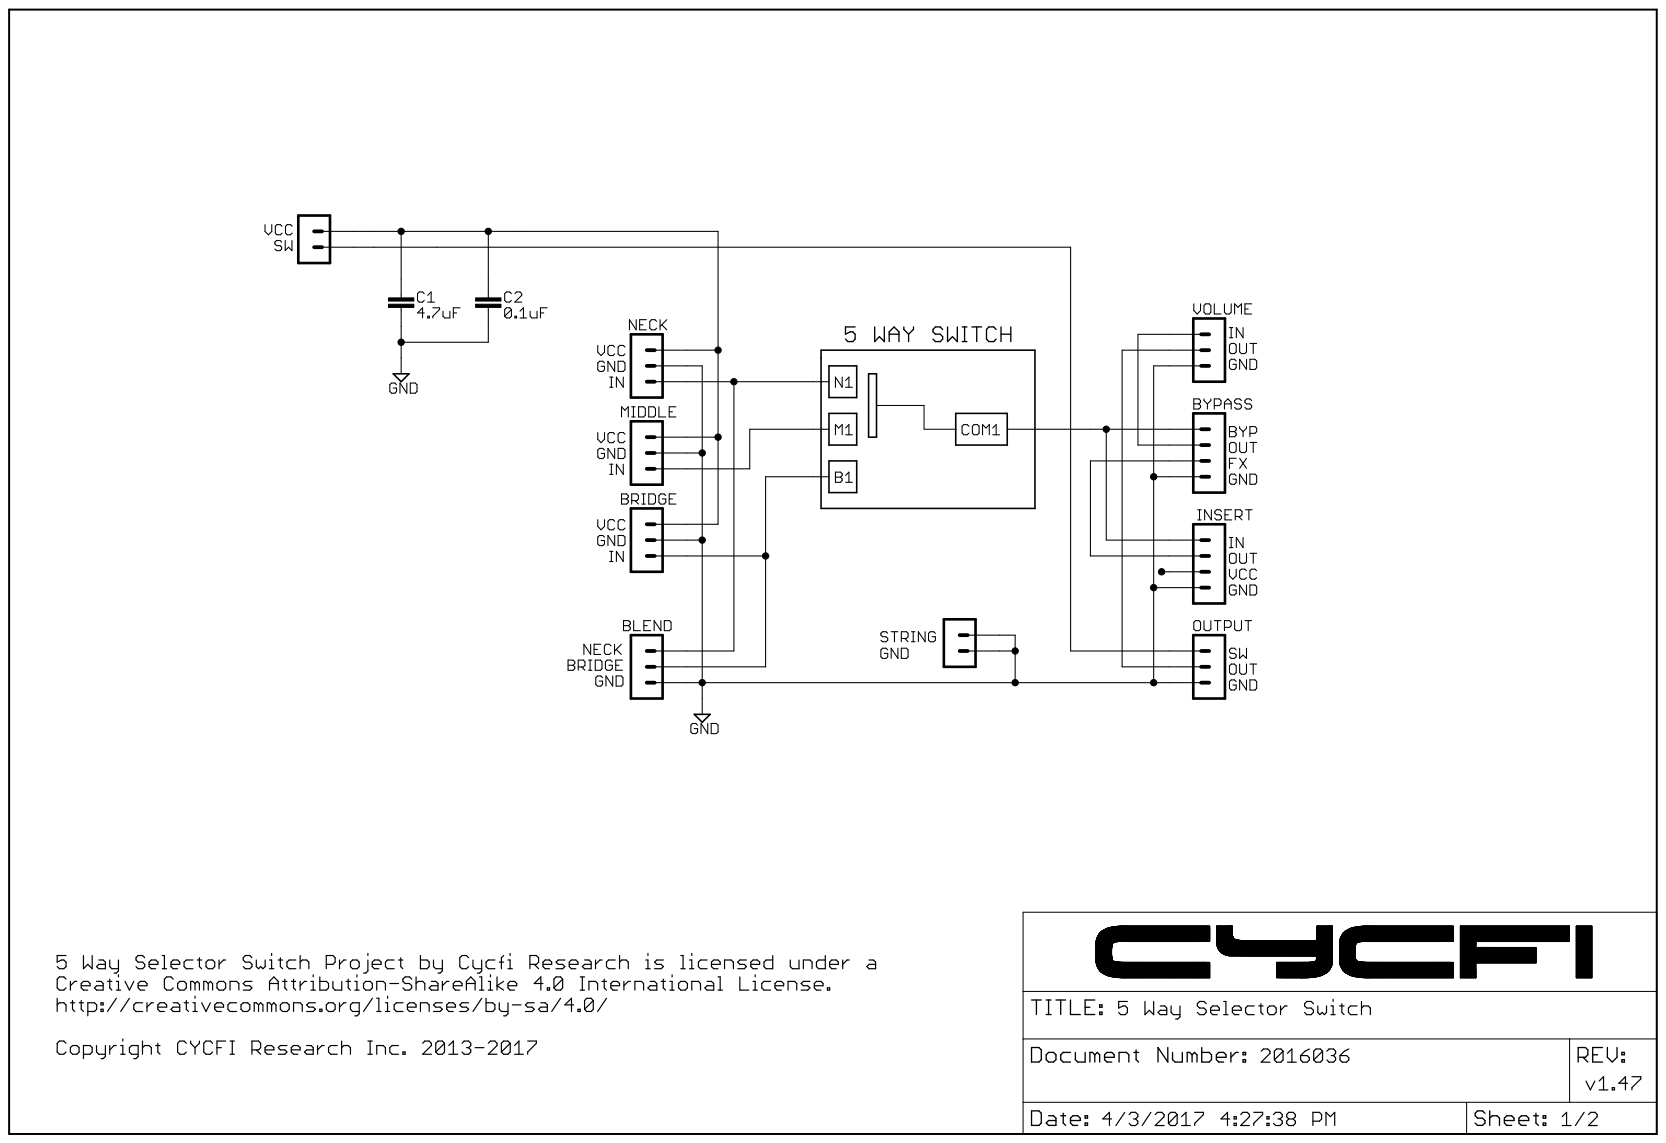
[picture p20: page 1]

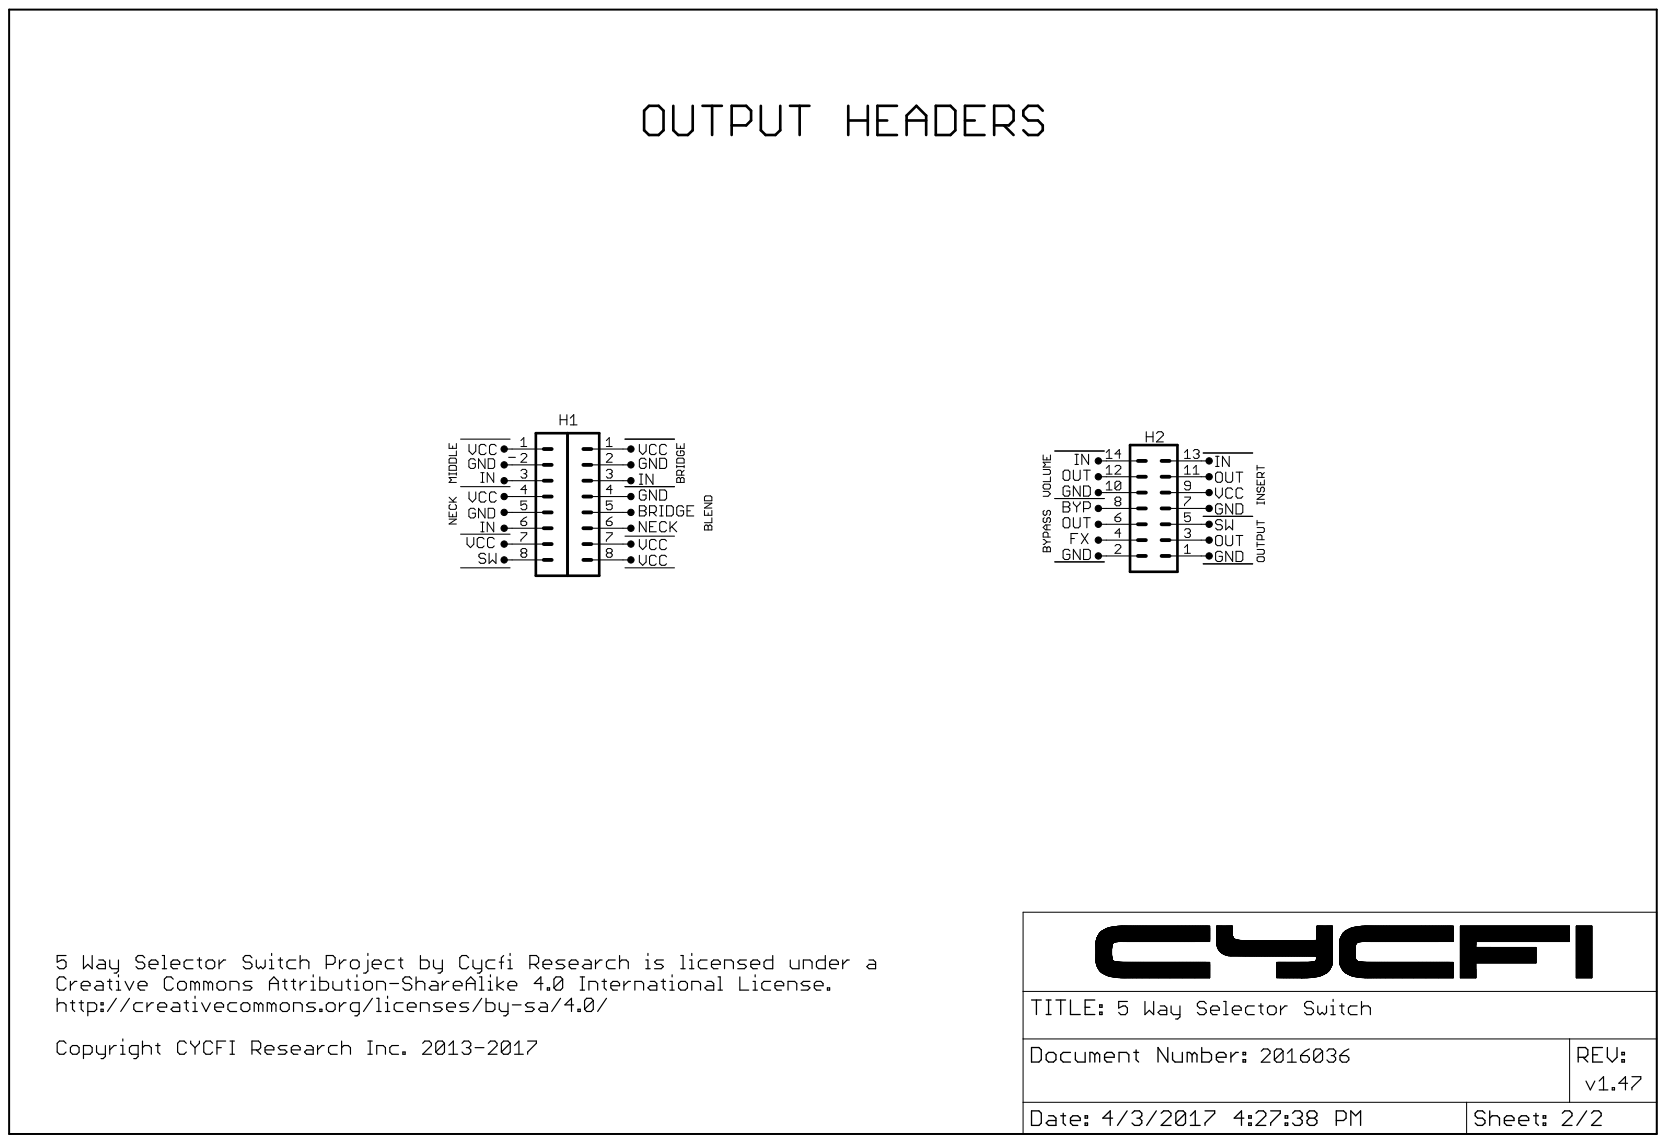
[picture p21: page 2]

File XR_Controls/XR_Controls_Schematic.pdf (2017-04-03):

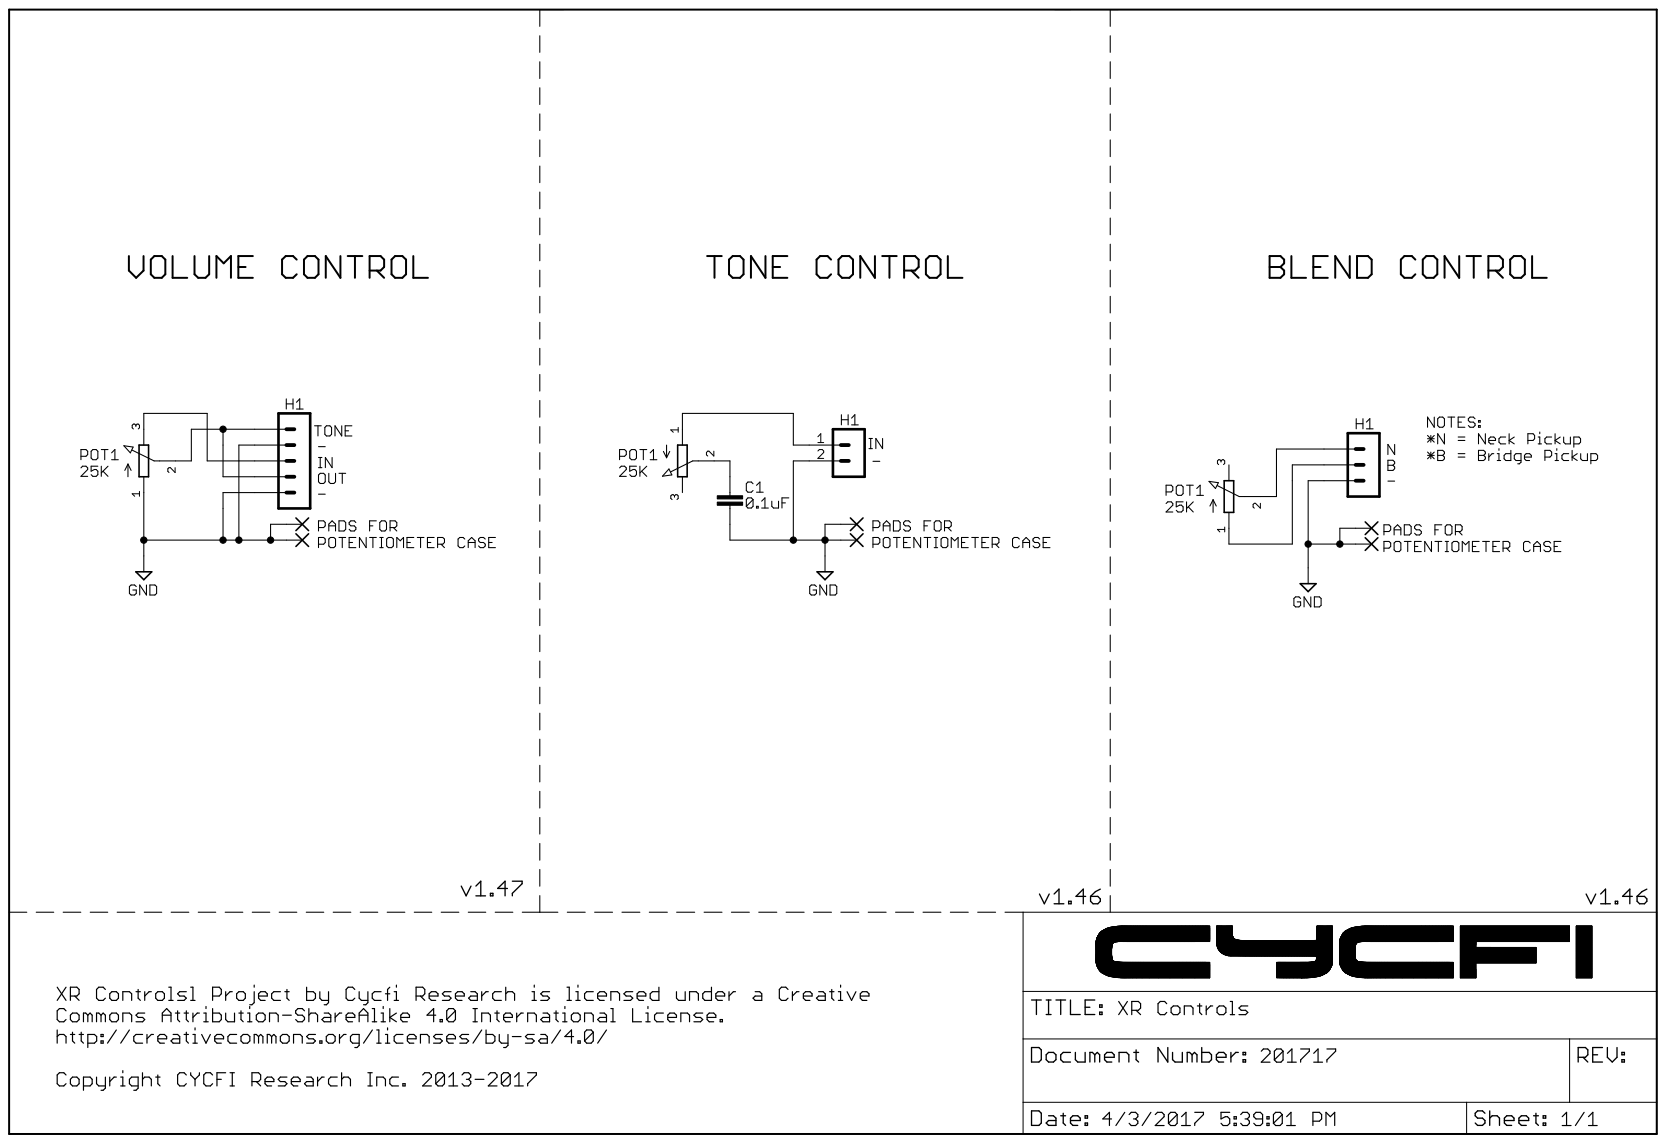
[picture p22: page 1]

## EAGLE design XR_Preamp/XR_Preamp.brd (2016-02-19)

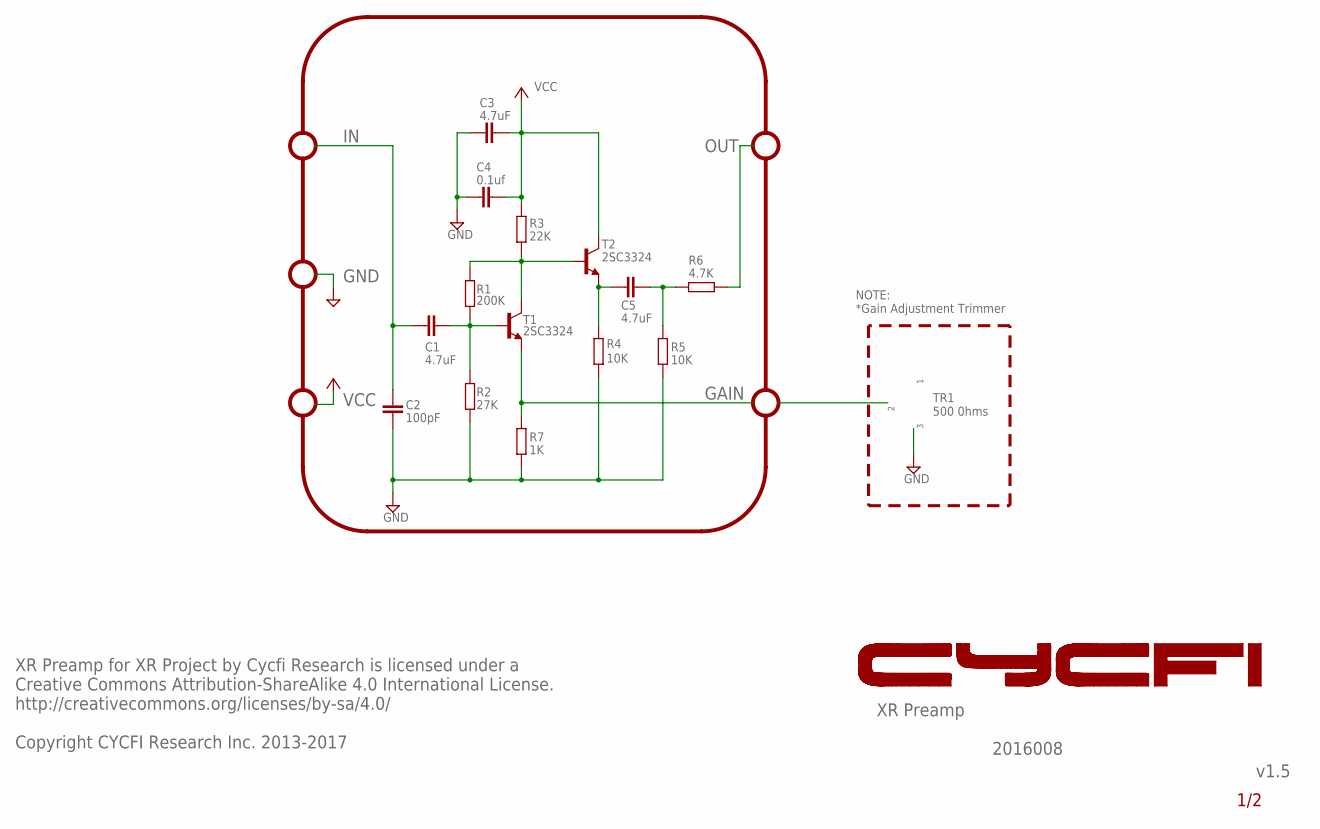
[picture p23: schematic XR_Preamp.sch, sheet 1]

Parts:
C1, C3: 4.7uF; C0603
C2: 100pF; C0402
C4: 0.1uf; C0402
C5: 4.7uF; C0402
R1: 200K; R0402
R2: 27K; R0402
R3: 22K; R0402
R4, R5: 10K; R0402
R6: 4.7K; R0402
R7: 1K; R0402
T1, T2: 2SC3324; SOT23

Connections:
GAIN: R7.2, T1.2 (E); also elsewhere on the board
GND: C2.1, C3.1, C4.1, R2.1, R4.1, R5.1, R7.1; also elsewhere on the board
IN: C1.1, C2.2; also elsewhere on the board
unnamed: C1.2, R1.1, R2.2, T1.1 (B)
unnamed: C5.2, R4.2, T2.2 (E)
OUT: R6.2; also elsewhere on the board
OUT1: C5.1, R5.2, R6.1
VCC: C3.2, C4.2, R3.2, T2.3 (C); also elsewhere on the board
VCVF: R1.2, R3.1, T1.3 (C), T2.1 (B)

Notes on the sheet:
TR1 500 0hms
NOTE: *Gain Adjustment Trimmer
XR Preamp
v1.5
XR Preamp for XR Project by Cycfi Research is licensed under a Creative Commons Attribution-ShareAlike 4.0 International License. http://creativecommons.org/licenses/by-sa/4.0/ Copyright CYCFI Research Inc. 2013-2017
2016008
1/2

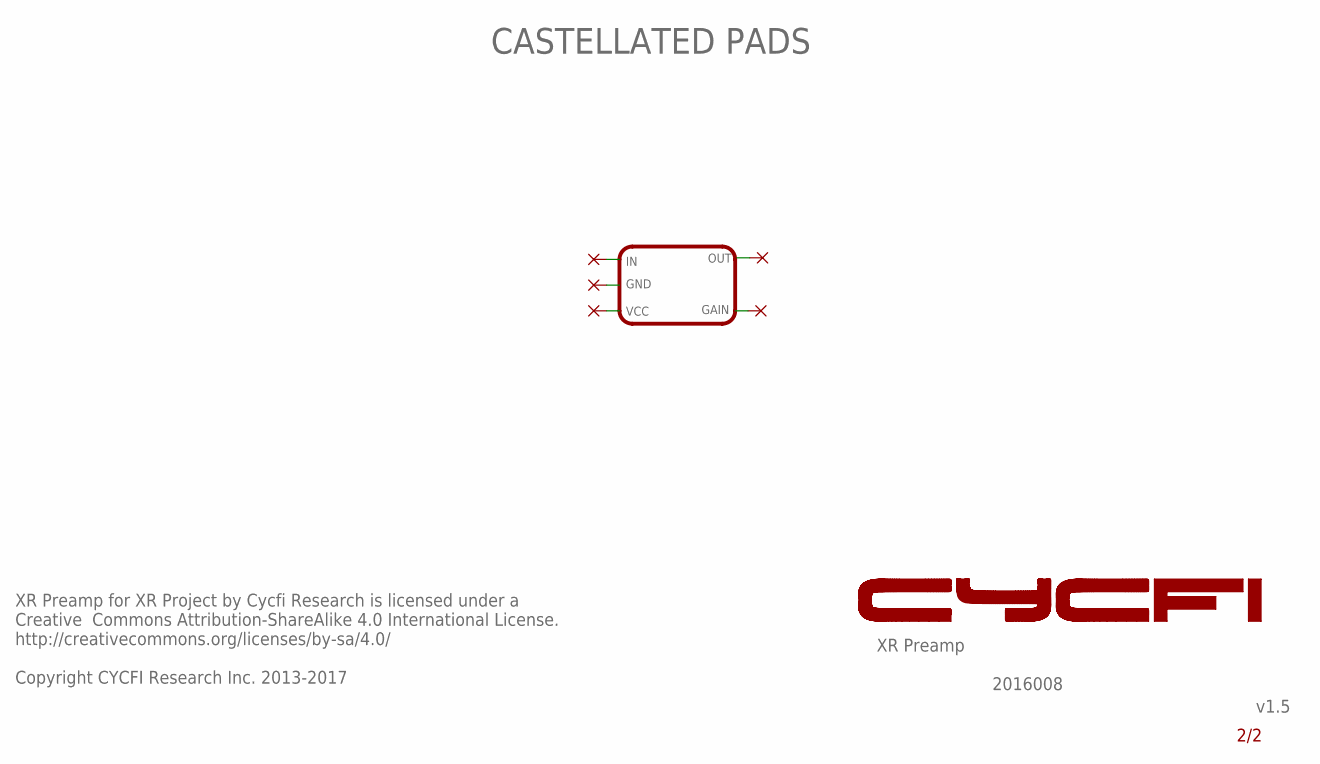
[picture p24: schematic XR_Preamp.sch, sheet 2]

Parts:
PAD1, PAD2, PAD3, PAD4, PAD5: WIREPAD2,15/1,0; 1,6/0,8

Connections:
GAIN: PAD1.1; also elsewhere on the board
GND: PAD2.1; also elsewhere on the board
IN: PAD3.1; also elsewhere on the board
OUT: PAD5.1; also elsewhere on the board
VCC: PAD4.1; also elsewhere on the board

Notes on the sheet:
GND
VCC
CASTELLATED PADS
XR Preamp
v1.5
XR Preamp for XR Project by Cycfi Research is licensed under a Creative Commons Attribution-ShareAlike 4.0 International License. http://creativecommons.org/licenses/by-sa/4.0/ Copyright CYCFI Research Inc. 2013-2017
2016008
2/2

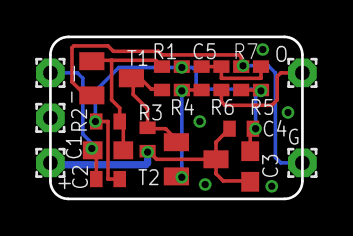
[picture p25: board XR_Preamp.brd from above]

Board: 2 copper layers, 14.0 x 9.0 mm, 19 parts (0 on the bottom side), 9 nets.

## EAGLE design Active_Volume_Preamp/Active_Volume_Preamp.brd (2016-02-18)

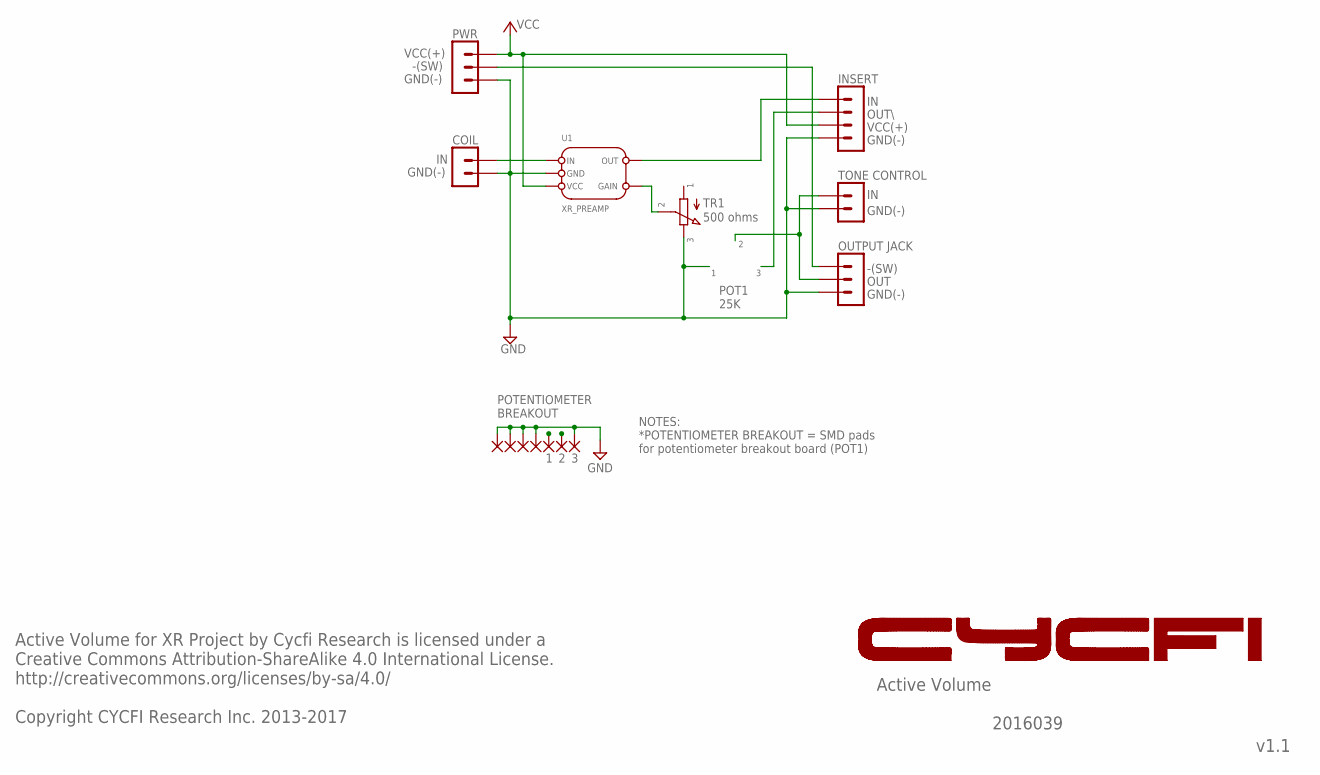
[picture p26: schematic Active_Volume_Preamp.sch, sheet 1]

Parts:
PAD1, PAD2, PAD3, PAD4, PAD5, PAD6, PAD7: SMD2; SMD1,27-2,54
TR1: TC33X-2-201E
U1: XR_PREAMP; XR_PREAMP_V1.5

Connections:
GND: PAD1.1, PAD4.1, PAD5.1, PAD6.1, PAD7.1, TR1.P$3 (3), U1.GND; also elsewhere on the board
INPUT: U1.IN; also elsewhere on the board
unnamed: TR1.P$2 (2), U1.GAIN
OUT(PREAMP): U1.OUT; also elsewhere on the board
OUT(SEL): PAD2.1; also elsewhere on the board
OUT(VOL): PAD3.1; also elsewhere on the board
VCC: U1.VCC; also elsewhere on the board

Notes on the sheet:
POTENTIOMETER BREAKOUT
POT1 25K
-(SW)
VCC(+)
GND(-)
OUT\
OUT
PWR
INSERT
OUTPUT JACK
COIL
TONE CONTROL
500 ohms
NOTES: *POTENTIOMETER BREAKOUT = SMD pads for potentiometer breakout board (POT1)
Active Volume
v1.1
Active Volume for XR Project by Cycfi Research is licensed under a Creative Commons Attribution-ShareAlike 4.0 International License. http://creativecommons.org/licenses/by-sa/4.0/ Copyright CYCFI Research Inc. 2013-2017
2016039

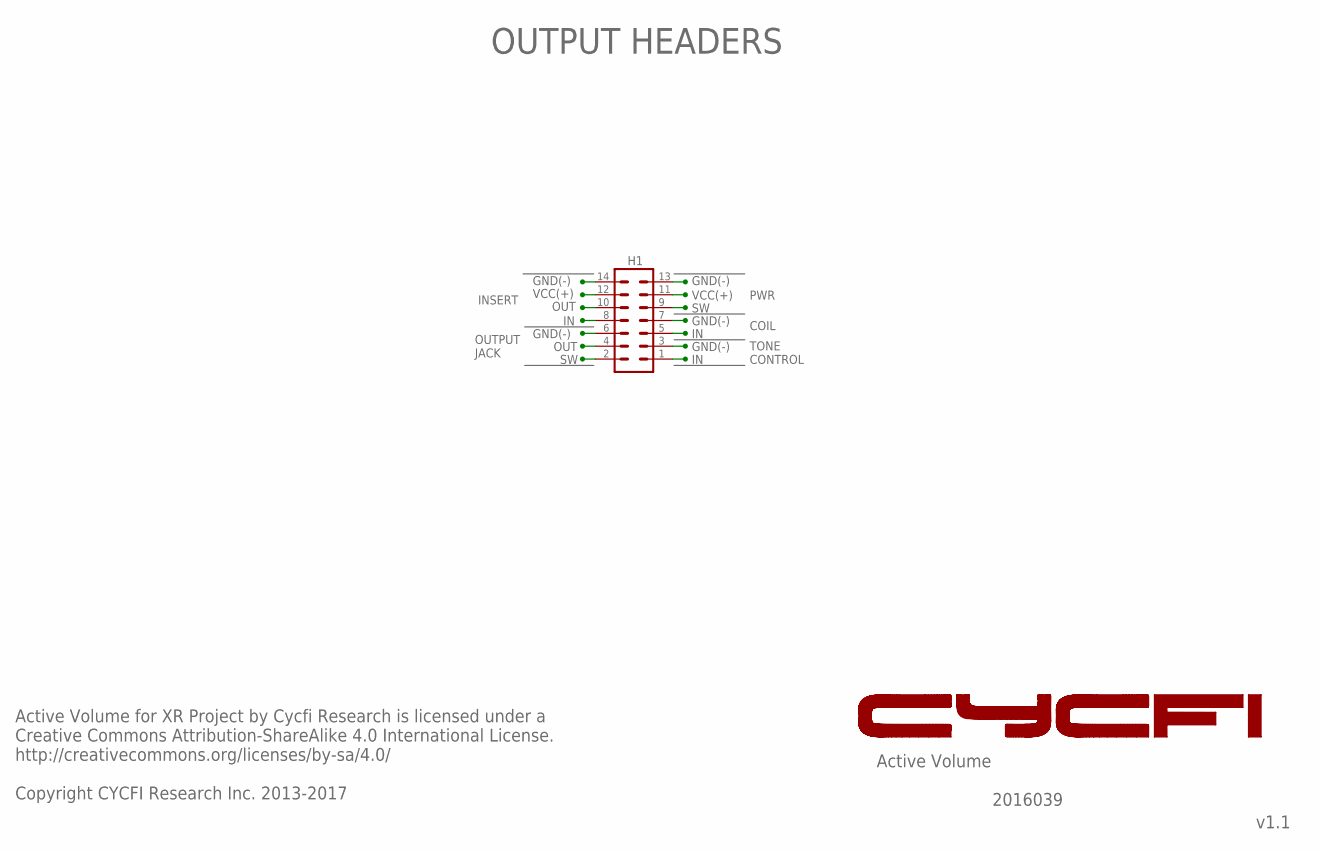
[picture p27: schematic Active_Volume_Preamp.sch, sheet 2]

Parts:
H1: MA07-2

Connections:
GND: H1.3, H1.6, H1.7, H1.13, H1.14; also elsewhere on the board
INPUT: H1.5; also elsewhere on the board
OUT(PREAMP): H1.8; also elsewhere on the board
OUT(SEL): H1.10; also elsewhere on the board
OUT(VOL): H1.1, H1.4; also elsewhere on the board
SW: H1.2, H1.9
VCC: H1.11, H1.12; also elsewhere on the board

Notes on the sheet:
OUT
Active Volume
v1.1
Active Volume for XR Project by Cycfi Research is licensed under a Creative Commons Attribution-ShareAlike 4.0 International License. http://creativecommons.org/licenses/by-sa/4.0/ Copyright CYCFI Research Inc. 2013-2017
2016039
GND(-)
VCC(+)
OUTPUT HEADERS
INSERT
OUTPUT JACK
PWR
TONE CONTROL
COIL

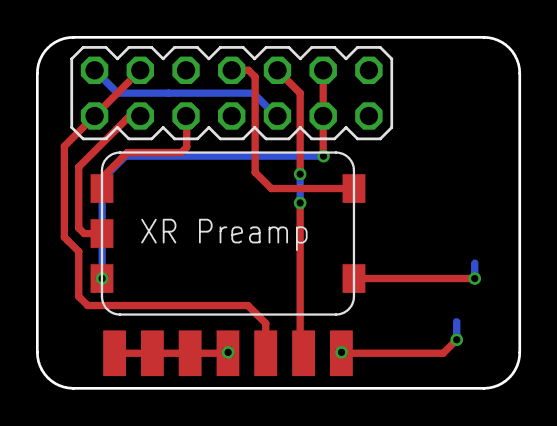
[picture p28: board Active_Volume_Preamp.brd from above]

Board: 2 copper layers, 26.8 x 19.5 mm, 10 parts (1 on the bottom side), 8 nets.

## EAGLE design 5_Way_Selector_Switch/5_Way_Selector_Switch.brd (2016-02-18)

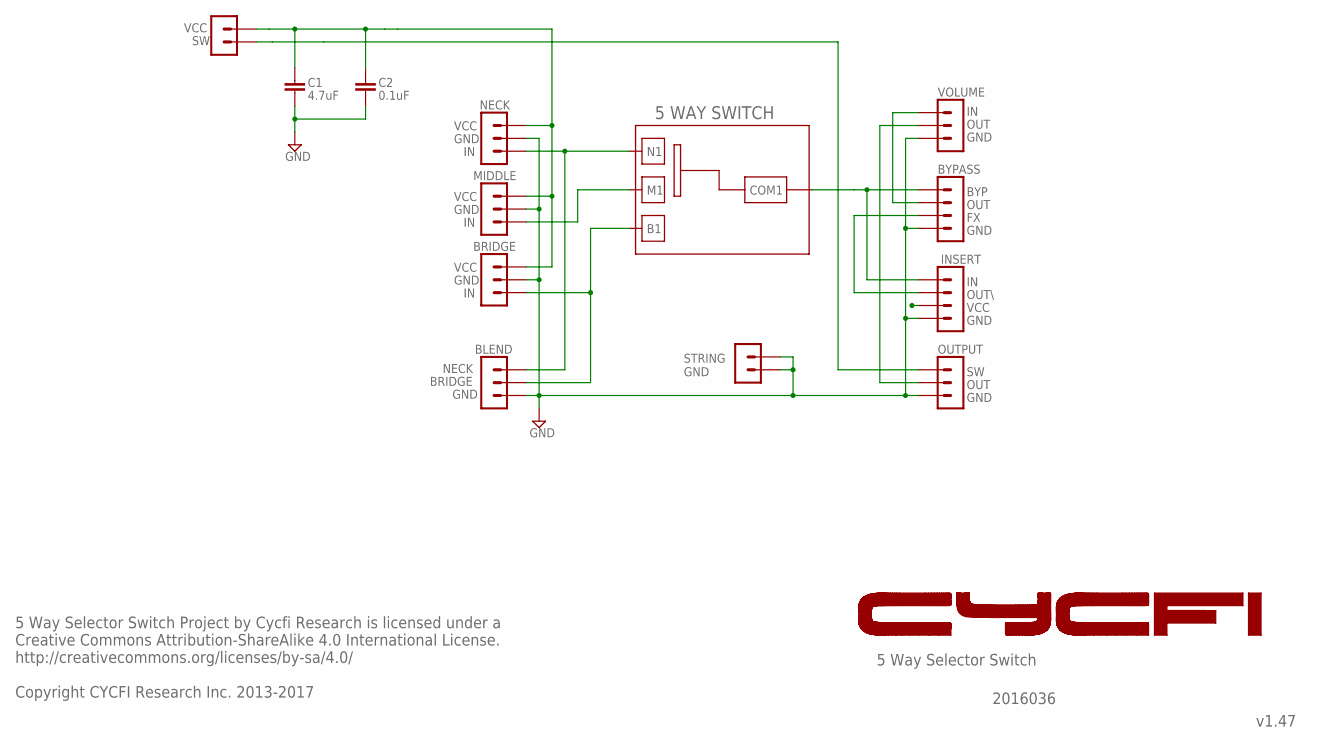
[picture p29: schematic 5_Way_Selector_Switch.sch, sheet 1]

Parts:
C1: 4.7uF; C0603
C2: 0.1uF; C0603
H3: 2PIN-SMD-2.54MM; 2P-SMD-2.54MM
U$3: 5WAY_SW_1; 5WAY_SW_CASTELLATED

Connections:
5WOUT: U$3.COM1; also elsewhere on the board
9V: C1.1, C2.1; also elsewhere on the board
B1: U$3.B1; also elsewhere on the board
GND: C1.2, C2.2, H3.P$1 (1), H3.P$2 (2); also elsewhere on the board
M1: U$3.M1; also elsewhere on the board
N1: U$3.N1; also elsewhere on the board

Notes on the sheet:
STRING GND
VCC
GND
NECK
BRIDGE
BLEND
BYP
OUT
OUT\
VOLUME
INSERT
OUTPUT
BYPASS
5 Way Selector Switch
v1.47
5 Way Selector Switch Project by Cycfi Research is licensed under a Creative Commons Attribution-ShareAlike 4.0 International License. http://creativecommons.org/licenses/by-sa/4.0/ Copyright CYCFI Research Inc. 2013-2017
2016036
MIDDLE

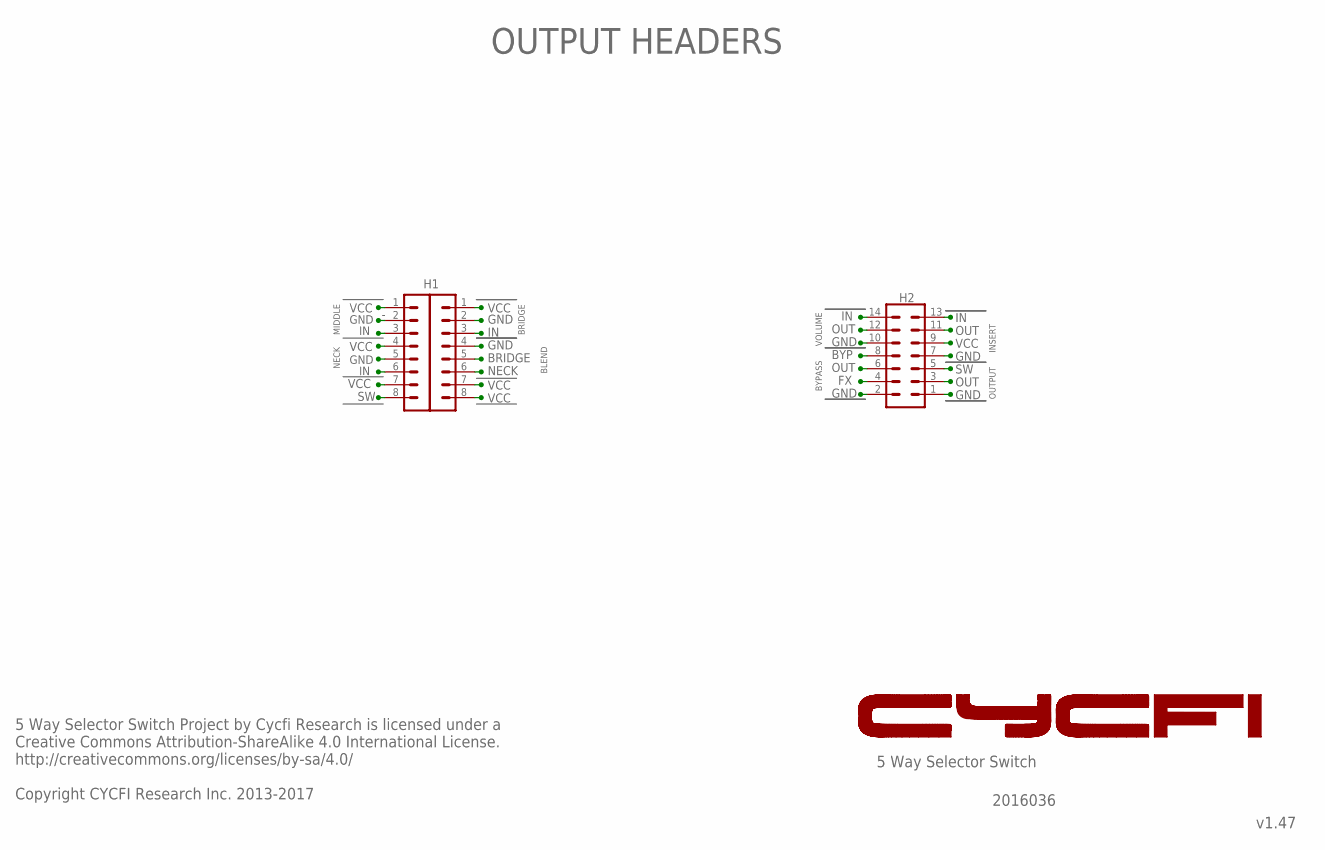
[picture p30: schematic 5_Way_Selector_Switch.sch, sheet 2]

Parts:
H2: MA07-2
SV1, SV2: MA08-1_

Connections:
5WOUT: H2.8, H2.13; also elsewhere on the board
9V: H2.9, SV1.1, SV1.7, SV1.8, SV2.1, SV2.4, SV2.7; also elsewhere on the board
B1: SV1.3, SV1.5; also elsewhere on the board
FX: H2.4, H2.11
GND: H2.1, H2.2, H2.7, H2.10, SV1.2, SV1.4, SV2.2, SV2.5; also elsewhere on the board
IN_VOL/MAIN_OUT: H2.6, H2.14
M1: SV2.3; also elsewhere on the board
N1: SV1.6, SV2.6; also elsewhere on the board
OUT(VOL): H2.3, H2.12
SW: H2.5, SV2.8

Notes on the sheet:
BYP
OUT
GND
VCC
NECK
BRIDGE
VOLUME
BYPASS
INSERT
OUTPUT
5 Way Selector Switch
v1.47
5 Way Selector Switch Project by Cycfi Research is licensed under a Creative Commons Attribution-ShareAlike 4.0 International License. http://creativecommons.org/licenses/by-sa/4.0/ Copyright CYCFI Research Inc. 2013-2017
2016036
OUTPUT HEADERS
BLEND
MIDDLE

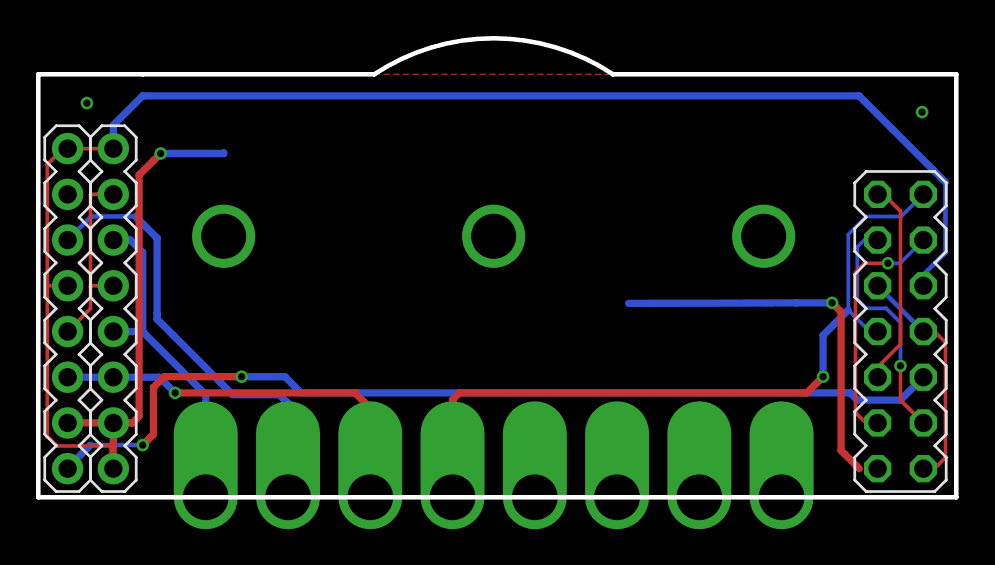
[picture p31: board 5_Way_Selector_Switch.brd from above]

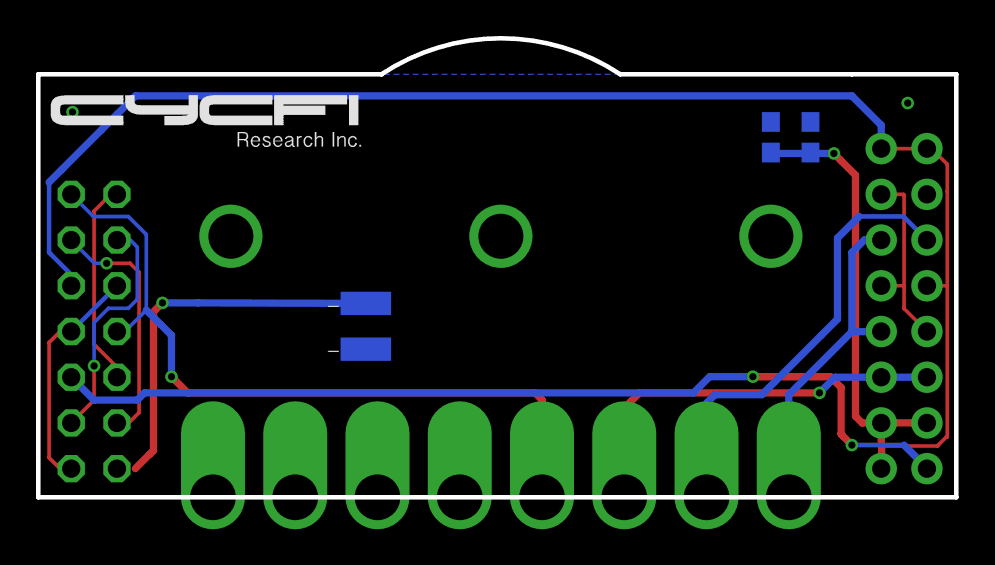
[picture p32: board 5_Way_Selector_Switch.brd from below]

Board: 2 copper layers, 51.0 x 25.5 mm, 7 parts (3 on the bottom side), 10 nets.

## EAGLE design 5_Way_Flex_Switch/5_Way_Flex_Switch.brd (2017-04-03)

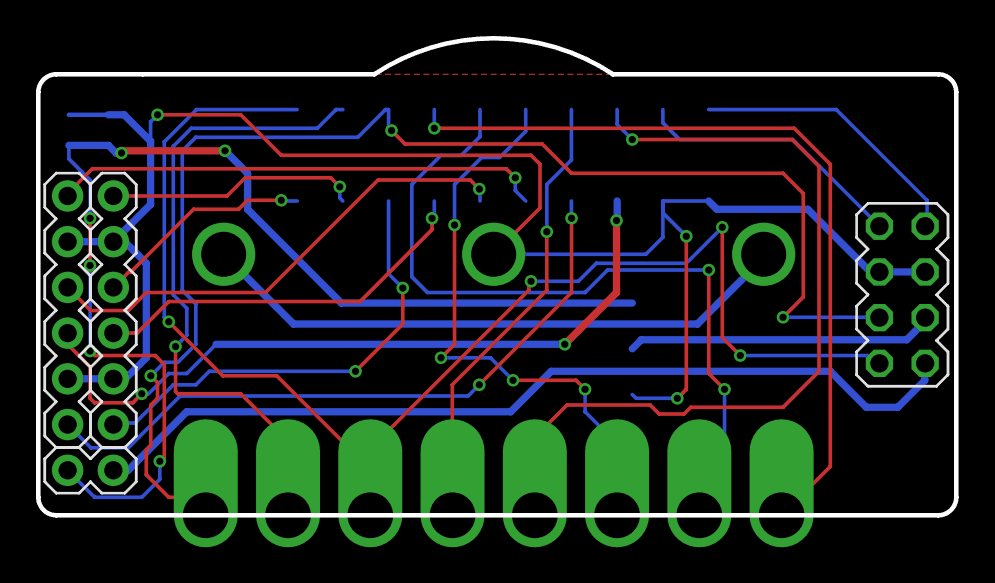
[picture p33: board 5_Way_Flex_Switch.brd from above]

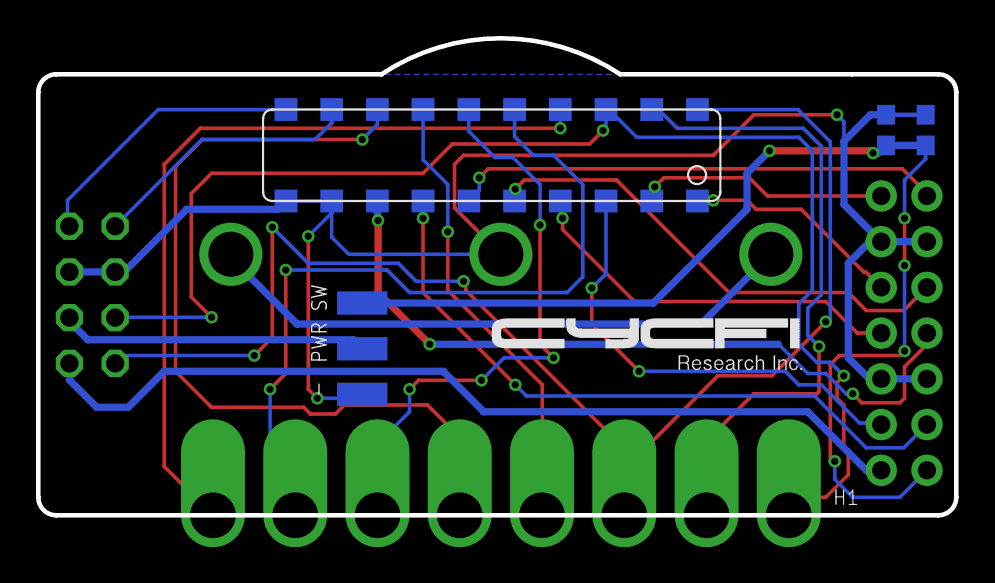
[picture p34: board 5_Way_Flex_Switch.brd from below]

Board: 2 copper layers, 51.0 x 26.5 mm, 9 parts (3 on the bottom side), 22 nets.

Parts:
C1: 4.7uF; C0603
C2: 0.1uF; C0603
CB1: CONFIGURATION_BRD_PADS
H1: MA02-1
H2: MA04-2
H3: 3PIN-SMD-2.54MM; 3P-SMD-2.54MM
H4, H5: MA06-1_
U$1: 5WAY_SW_CASTELLATED

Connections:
1-IC: CB1.1-IC, H4.3
1-OC: CB1.1-OC, H4.1
2-IC: CB1.2-IC, H4.6
2-OC: CB1.2-OC, H4.4
3-IC: CB1.3-IC, H5.3
3-OC: CB1.3-OC, H5.1
4-IC: CB1.4-IC, H5.6
4-OC: CB1.4-OC, H5.4
B1: CB1.B1, H2.4, U$1.B1
GND: C1.2, C2.2, CB1.GND, CB1.GND1, H2.5, H2.6, H3.P$3, H4.2, H4.5, H5.2, H5.5
IN+: CB1.OUT-, H2.7
IN-: CB1.OUT+, H2.8
N1: CB1.N1, H2.2, U$1.N1
unnamed: CB1.COM2, U$1.COM2
unnamed: CB1.COM1, U$1.COM1
unnamed: CB1.M1, U$1.M1
unnamed: CB1.N2, U$1.N2
unnamed: CB1.M2, U$1.M2
unnamed: CB1.B2, U$1.B2
SW: H1.1, H2.1
VBATT: C1.1, C2.1, H1.2, H3.P$1
VCC: H2.3, H3.P$2

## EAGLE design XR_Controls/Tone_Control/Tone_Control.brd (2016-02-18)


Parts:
C1: 0.1uF; C0603
GND3, GND4: SMD2; SMD1,27-2,54
H1: MA02-1
POT1: PDB181-GTR01; PDB181

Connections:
GND: C1.1, GND3.1, GND4.1, H1.2
unnamed: C1.2, POT1.P$2 (2)
unnamed: H1.1, POT1.P$1 (1)

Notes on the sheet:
PADS FOR POTENTIOMETER CASE
POT1 25K
Tone Control
v1.46
XR Controls Project by Cycfi Research is licensed under a Creative Commons Attribution-NonCommercial 4.0 International License. http://creativecommons.org/licenses/by-nc/4.0/ Copyright CYCFI Research Inc. 2013-2016
2016040



Board: 2 copper layers, 23.0 x 23.5 mm, 5 parts (2 on the bottom side), 3 nets.

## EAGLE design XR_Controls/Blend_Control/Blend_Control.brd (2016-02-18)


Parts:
GND3, GND4: SMD2; SMD1,27-2,54
H1: 3PIN-SMD-2.54MM; 3P-SMD-2.54MM
POT1: PDB181-GTR01; PDB181

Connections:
GND: GND3.1, GND4.1, H1.P$1 (1)
unnamed: H1.P$3 (3), POT1.P$2 (2)
unnamed: H1.P$2 (2), POT1.P$1 (1)

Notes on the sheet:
PADS FOR POTENTIOMETER CASE
NOTES: *N = Neck Pickup *B = Bridge Pickup
POT1 25K
Blend Control
v1.46
XR Controls Project by Cycfi Research is licensed under a Creative Commons Attribution-NonCommercial 4.0 International License. http://creativecommons.org/licenses/by-nc/4.0/ Copyright CYCFI Research Inc. 2013-2016
2016040


Board: 2 copper layers, 19.0 x 20.5 mm, 4 parts (1 on the bottom side), 3 nets.

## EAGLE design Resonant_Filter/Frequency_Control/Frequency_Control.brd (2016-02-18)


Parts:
C1, C2: 3.3nF; C0805
H1: MA04-1
PAD1: 1,6/0,9
POT1-A: PDB182-GTR02; PDB182-GTR01
R1, R2: 3.3K; R0603
R3, R4: 100K; R0402

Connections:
1: H1.1, R1.1
2: C1.2, H1.2
3: C2.1, H1.3, POT1-A.B2 (2), R4.2
GND: C2.2, H1.4, PAD1.1
unnamed: POT1-A.A3 (3), R1.2, R3.2
unnamed: C1.1, POT1-A.A2 (2), R2.1, R3.1
unnamed: POT1-A.B3 (3), R2.2, R4.1

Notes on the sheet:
POT1-A 100K
POT1-B 100K
SOLDERING PAD FOR POTENTIOMETER CASE
Frequency Control
v1.46
Resonant Filter Project by Cycfi Research is licensed under a Creative Commons Attribution-NonCommercial 4.0 International License. http://creativecommons.org/licenses/by-nc/4.0/ Copyright CYCFI Research Inc. 2013-2016
2016041



Board: 2 copper layers, 16.2 x 18.5 mm, 9 parts (6 on the bottom side), 7 nets.

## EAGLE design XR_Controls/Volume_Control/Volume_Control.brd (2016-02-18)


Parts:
GND3, GND4: SMD2; SMD1,27-2,54
H1: 961105-5500-AR-PR; 5P-SMD-2.54MM
POT1: PDB241-GTR01; PDB241

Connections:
GND: GND3.1, GND4.1, H1.P$1, H1.P$4, POT1.P$1 (1)
unnamed: H1.P$3, POT1.P$3 (3)
unnamed: H1.P$2, H1.P$5, POT1.P$2 (2)

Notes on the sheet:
OUT
TONE
PADS FOR POTENTIOMETER CASE
POT1 25K
Volume Control
v1.47
XR Controls Project by Cycfi Research is licensed under a Creative Commons Attribution-NonCommercial 4.0 International License. http://creativecommons.org/licenses/by-nc/4.0/ Copyright CYCFI Research Inc. 2013-2016
2016040


Board: 2 copper layers, 24.4 x 21.5 mm, 4 parts (1 on the bottom side), 3 nets.

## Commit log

2016-02-19 Directory/Files Restructure
    [Blend_Control.brd, Blend_Control.sch, Frequency_Control.brd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]
2016-02-19 Added Preamp V 1.5
    [XR_Preamp.brd, XR_Preamp.sch]
2016-02-23 Updates/ label modifications to make them consistent
    [5_Way_Flex_Switch.brd, 5_Way_Flex_Switch.sch, 5_Way_Selector_Switch.sch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]
2016-10-15 Rename and update drawings
    [Mounting_Base_Dual.dxf, Mounting_Base_Full_Width_Soapbar.dxf, Mounting_Base_Half_Width_Soapbar.dxf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]
2017-02-14 *organize 5-waay switch and its configuration board(a and b) *update license date *remove red frame schem pdf files, change with black frame *update document number
    [5_Way_Flex_Switch.sch, 5_Way_Selector_Switch.brd, 5_Way_Selector_Switch.sch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]
2017-02-14 * correct misspelled word
    [5_Way_Flex_Switch.sch]
2017-04-03 Updated schematic licenses
    [5_Way_Flex_Switch.sch, 5_Way_Selector_Switch.sch, Active_Volume.sch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]
2017-04-03 Updated schematic licenses.
    [5_Way_Selector_Switch.brd]
2017-04-04 Updated broken .sch files
    [5_Way_Flex_Switch.sch, Active_Volume.sch, Blend_Control.sch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]
2017-06-02 initial commit 5-Way Schematic
2017-09-05 Updated BOM and Document Number
    [Active_Volume_Preamp.brd, Active_Volume_Preamp.sch, Resonant_Filter.sch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]

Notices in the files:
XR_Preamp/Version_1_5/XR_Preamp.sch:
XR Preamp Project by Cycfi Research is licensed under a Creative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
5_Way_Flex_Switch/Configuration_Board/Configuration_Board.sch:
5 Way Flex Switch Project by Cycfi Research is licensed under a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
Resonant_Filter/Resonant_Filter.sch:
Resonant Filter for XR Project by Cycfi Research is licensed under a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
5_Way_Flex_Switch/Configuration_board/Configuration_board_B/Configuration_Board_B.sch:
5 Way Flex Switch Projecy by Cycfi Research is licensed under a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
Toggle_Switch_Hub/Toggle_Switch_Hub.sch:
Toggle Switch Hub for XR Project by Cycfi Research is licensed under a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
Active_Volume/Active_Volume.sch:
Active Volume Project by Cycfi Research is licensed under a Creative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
